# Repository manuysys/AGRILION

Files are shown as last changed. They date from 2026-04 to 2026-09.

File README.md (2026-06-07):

# 🌾 Agrilion

### Sistema inteligente de monitoreo para silobolsas

Agrilion es un sistema IoT diseñado para monitorear en tiempo real el
estado de granos almacenados en silobolsas, permitiendo detectar
condiciones de riesgo antes de que ocurran pérdidas económicas.

------------------------------------------------------------------------

## 🚀 Características principales

-   Comunicación LoRa de largo alcance\
-   Batería de larga duración (6--12 meses)\
-   Sensores de temperatura, humedad y gases\
-   Envío de datos cada 1--2 horas\
-   Visualización web\
-   Sistema de alertas tempranas\
-   Preparado para integración con IA

------------------------------------------------------------------------

## 🏗️ Arquitectura

Sensores → Dispositivo IoT (CubeCell) → LoRa → Gateway → Backend →
Dashboard

------------------------------------------------------------------------

## ⚙️ Tecnologías

-   Hardware: CubeCell + sensores\
-   Comunicación: LoRa / MQTT\
-   Backend: Firebase\
-   Frontend: Flutter Web\
-   Procesamiento: Python

------------------------------------------------------------------------

## ⚠️ Alertas

-   Humedad alta → posible filtración\
-   Temperatura elevada → actividad microbiana\
-   CO₂ alto → deterioro del grano

Estados: - Normal\
- Advertencia\
- Riesgo

------------------------------------------------------------------------

## 📊 Estado

-   Comunicación: OK\
-   Backend: OK\
-   Visualización: Básica\
-   Alertas: En desarrollo\
-   IA: En desarrollo

------------------------------------------------------------------------

## 🎯 Objetivo

Reducir pérdidas agrícolas mediante monitoreo inteligente y alertas
tempranas.

------------------------------------------------------------------------

## 👨‍💻 Autor

Juan Manuel Iglesias\
Proyecto Agrilion --- 2026

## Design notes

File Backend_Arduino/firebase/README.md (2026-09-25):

# Firebase Credentials

Este directorio contiene las credenciales de Firebase para el backend de AGRILION.

## ⚠️ IMPORTANTE

**NUNCA subas credenciales a Git.** Este directorio está protegido por `.gitignore`.

## Configuración

1. Ir a [Firebase Console](https://console.firebase.google.com/)
2. Seleccionar tu proyecto
3. Ir a **Project Settings** → **Service accounts**
4. Click en **Generate new private key**
5. Descargar el archivo JSON
6. Renombrarlo a `serviceAccountKey.json`
7. Colocarlo en este directorio: `Backend_Arduino/firebase/serviceAccountKey.json`

## Archivo Requerido

```
Backend_Arduino/firebase/serviceAccountKey.json
```

Este archivo es usado por:
- `MQTT_INFLUXDB_FIREBASE.py` — para actualizar datos categóricos en Firestore
- El script necesita permisos de escritura en las colecciones:
  - `sensors/{deviceId}` — estado de sensores
  - `users/{uid}/silos/{siloId}` — estado de silobolsas

## Estructura de Firestore

Ver `Inteligencia_Artificial/firestore.rules` para las reglas de seguridad completas.

### Colecciones usadas por el backend:

```
sensors/{deviceId}
  ├── ownerUid: string
  ├── siloId: string
  ├── active: boolean
  └── lastSeen: timestamp

users/{uid}/silos/{siloId}
  ├── estado: string (OK, RIESGO_MEDIO, RIESGO_ALTO)
  ├── alerta: string | null
  ├── score: number
  ├── evento: string | null
  ├── delta_co2: number
  └── ultima_actualizacion: timestamp
```

## Troubleshooting

### Error: "Firebase credentials not found"
Verificar que `firebase/serviceAccountKey.json` existe en este directorio.

### Error: "Permission denied"
Verificar que el service account tiene permisos de escritura en Firestore.

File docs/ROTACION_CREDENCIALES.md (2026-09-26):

# 🔐 Rotación de credenciales LoRaWAN (CubeCell / TTN)

Las credenciales OTAA del firmware estuvieron publicadas en el repositorio
(`devEui`, `appEui`, `appKey`). Ya se movieron a `secrets.h` (ignorado por git),
pero **hay que rotar el AppKey en TTN** para invalidar el que quedó público.

End device actual:

| Campo | Valor |
|---|---|
| End device ID | `smisia-cubecellab02s` |
| DevEUI | `70B3D57ED0076DC9` |
| JoinEUI (AppEUI) | `A2F42E5BA39F0F21` |
| Región | AU915 FSB2 |
| Activación | OTAA (LoRaWAN 1.0.2) |

---

## 1. Generar un AppKey nuevo en TTN

1. TTN Console → **Applications** → tu aplicación → **End devices** →
   `smisia-cubecellab02s`.
2. **General settings → Network layer → AppKey**.
3. Click en **Generate new AppKey** (o editar a mano un valor de 16 bytes) →
   **Save changes**.
4. Copiar el AppKey nuevo (hex de 32 caracteres).

> El DevEUI y el JoinEUI no hace falta cambiarlos (identifican el hardware y la
> aplicación; no son secretos). El AppKey es el secreto que se usa en el join.

## 2. Actualizar `secrets.h`

1. Copiar la plantilla si todavía no existe:

```bash
cd Backend_Arduino/Codigo_TransmisionLoraWAN_Sensores
copy secrets.h.example secrets.h
```

2. Editar `secrets.h` y pegar el AppKey nuevo:

```c
uint8_t devEui[] = { 0x70, 0xB3, 0xD5, 0x7E, 0xD0, 0x07, 0x6D, 0xC9 };
uint8_t appEui[] = { 0xA2, 0xF4, 0x2E, 0x5B, 0xA3, 0x9F, 0x0F, 0x21 };
uint8_t appKey[] = { 0x00, ... };  // ← reemplazar por el AppKey nuevo
```

> `secrets.h` está en `.gitignore`: nunca se sube al repo.

## 3. Reflashear y reiniciar la sesión

1. Abrir `Codigo_TransmisionLoraWAN_Sensores.ino` en Arduino IDE
   (placa CubeCell, región AU915).
2. Compilar y subir al dispositivo.
3. En TTN Console → End device → **Reset session** (borra la sesión vieja).
4. Encender el equipo: el log serie debe mostrar
   `DEVICE_STATE_INIT → JOIN → SEND → SLEEP`.
5. En TTN Console → **Live data** deben aparecer los uplinks con
   `decoded_payload` (temperatura, humedad, presion, co2, impacto, aceleracion).

## 4. Verificar que el payload se decodifica

El formatter tiene que estar pegado en
**TTN Console → Applications → Payload formatters → Uplink**:
copiar el contenido de `Backend_Arduino/TTN_Payload_Formatter.js`.

Payload esperado (11 bytes):

| Bytes | Campo | Escala |
|---|---|---|
| 0-1 | temperatura | ×100 (int16 BE) |
| 2-3 | humedad | ×100 (int16 BE) |
| 4-5 | presión | ×10 (int16 BE) |
| 6-7 | CO₂ | ppm (uint16 BE) |
| 8 | flag de impacto | 0/1 |
| 9-10 | aceleración | ×10 (uint16 BE) |

## 5. Chequeo rápido

- TTN Live data: llega un uplink cada ~20 s (configurable en `appTxDutyCycle`).
- HiveMQ: mensajes en `smisia/smisia-cubecellab02s`.
- InfluxDB: `SELECT * FROM "sensores" WHERE device = 'smisia-cubecellab02s' ORDER BY time DESC LIMIT 5`.
- Web: `/dashboard` y `/dashboard/silo/{id}` con la última lectura.

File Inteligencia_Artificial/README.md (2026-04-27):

# AGRILION 🌾

## Sistema ML de Análisis de Silobolsas Agrícolas

AGRILION es un sistema completo de Machine Learning para monitoreo y análisis predictivo de silobolsas agrícolas. Utiliza datos de sensores (temperatura, humedad, CO2) recolectados vía LoRa para detectar riesgos de deterioro del grano antes de que generen pérdidas.

---

## 📋 Características

- **Series Temporales**: Análisis de datos de sensores con LSTM
- **Detección de Anomalías**: 3 métodos (Z-Score, Moving Average, Isolation Forest) con consenso
- **Predicción**: Forecasting single-step y multi-step con LSTM
- **Scoring de Riesgo**: Motor ponderado (0-100) con reglas agronómicas
- **Alertas Inteligentes**: Alertas contextualizadas en español con recomendaciones
- **API REST**: FastAPI con endpoints de predicción y análisis
- **Visualización**: Gráficos profesionales con estilo dark theme

---

## 🏗️ Estructura del Proyecto

```
agrilion/
├── src/                         # Paquete principal
│   ├── __init__.py
│   ├── config.py                # Configuración centralizada
│   ├── data_loader.py           # Carga y limpieza de datos
│   ├── preprocessing.py         # Normalización y windowing LSTM
│   ├── anomaly_detection.py     # Detección de anomalías (3 métodos)
│   ├── lstm_model.py            # Modelo LSTM (TensorFlow/Keras)
│   ├── predictor.py             # Predicción y evaluación
│   ├── risk_engine.py           # Motor de riesgo agronómico
│   ├── alerts.py                # Sistema de alertas inteligentes
│   └── visualization.py         # Gráficos profesionales
├── api/                         # FastAPI
│   ├── __init__.py
│   ├── app.py                   # Aplicación FastAPI
│   ├── schemas.py               # Modelos Pydantic
│   └── routes.py                # Endpoints REST
├── data/                        # Datos
│   └── synthetic_generator.py   # Generador de datos sintéticos
├── models/                      # Modelos entrenados (.keras)
├── outputs/                     # Gráficos generados
├── tests/                       # Tests unitarios
│   └── test_pipeline.py
├── main.py                      # Pipeline completo
├── requirements.txt             # Dependencias
└── README.md
```

---

## 🚀 Instalación

```bash
# Clonar o navegar al proyecto
cd src

# Crear entorno virtual (recomendado)
python -m venv venv
venv\Scripts\activate          # Windows
# source venv/bin/activate    # Linux/Mac

# Instalar dependencias
pip install -r requirements.txt
```

---

## ▶️ Uso Rápido

### Pipeline Completo
```bash
# Ejecutar pipeline end-to-end (genera datos sintéticos si no existen)
python main.py

# Con datos propios
python main.py --data path/to/sensor_data.csv

# Personalizar entrenamiento
python main.py --epochs 100 --batch-size 64

# Usar modelo ya entrenado (sin re-entrenar)
python main.py --skip-training

# Sin gráficos
python main.py --no-plots
```

### API REST
```bash
# Iniciar la API
uvicorn api.app:app --reload --port 8000

# Documentación interactiva
# http://localhost:8000/docs
```

### Endpoints de la API

| Método | Endpoint | Descripción |
|---|---|---|
| `GET`  | `/api/v1/health` | Health check |
| `GET`  | `/api/v1/model/status` | Estado del modelo |
| `POST` | `/api/v1/predict` | Predicción de valores futuros |
| `POST` | `/api/v1/analyze` | Análisis completo (anomalías + riesgo + alertas) |

#### Ejemplo: Predicción
```bash
curl -X POST http://localhost:8000/api/v1/predict \
  -H "Content-Type: application/json" \
  -d '{
    "readings": [...],  # 24+ lecturas de sensores
    "steps": 6          # Pasos futuros a predecir
  }'
```

---

## 🧠 Arquitectura del Modelo LSTM

```
Input(24 timesteps, 3 features)
    → LSTM(128, return_sequences=True)
    → Dropout(0.2)
    → LSTM(64)
    → Dropout(0.2)
    → Dense(32, ReLU)
    → Dense(3)  # Predicción multivariable
```

- **Ventana de entrada**: 24 mediciones (~24 horas)
- **Optimizador**: Adam (lr=0.001)
- **Loss**: MSE
- **Callbacks**: EarlyStopping + ReduceLROnPlateau

---

## 🔍 Detección de Anomalías

| Método | Tipo | Parámetros |
|---|---|---|
| **Z-Score** | Estadístico | threshold=3.0σ |
| **Moving Average** | Tendencia local | window=12, threshold=2.0σ |
| **Isolation Forest** | ML no supervisado | contamination=5% |

**Consenso**: Una anomalía se confirma si ≥2 de 3 métodos la detectan.

---

## ⚠️ Motor de Riesgo

### Factores Ponderados

| Factor | Peso | Lógica |
|---|---|---|
| Humedad + Temperatura | 30% | Sinergia hongos/bacterias |
| CO2 | 25% | Actividad biológica / fermentación |
| Anomalías estadísticas | 20% | Proporción en ventana reciente |
| Desviación LSTM | 25% | Error de predicción normalizado |

### Niveles de Riesgo

| Score | Nivel | Significado |
|---|---|---|
| 0–30 | 🟢 NORMAL | Operación segura |
| 30–70 | 🟡 WARNING | Monitoreo recomendado |
| 70–100 | 🔴 CRITICAL | Acción urgente requerida |

---

## 📊 Gráficos Generados

1. **Series Temporales**: Visualización completa de sensores
2. **Predicciones vs Reales**: Overlay con métricas R²/MAE
3. **Anomalías Detectadas**: Series con puntos anómalos marcados
4. **Timeline de Riesgo**: Zonas de color por nivel
5. **Historial de Entrenamiento**: Loss y MAE por época

---

## 🧪 Tests

```bash
# Ejecutar todos los tests
python -m pytest tests/ -v

# Tests específicos
python -m pytest tests/test_pipeline.py::TestRiskEngine -v
```

---

## 📡 Formato de Datos

### CSV de Entrada
```csv
timestamp,temperature,humidity,co2,silo_id
2025-01-15 00:00:00,24.5,62.3,418.0,SILO_001
2025-01-15 01:00:00,23.8,64.1,422.5,SILO_001
...
```

### Columnas Requeridas
- `timestamp`: Fecha y hora (ISO 8601)
- `temperature`: Temperatura en °C
- `humidity`: Humedad relativa en %
- `co2`: Dióxido de carbono en ppm

---

## 🔧 Configuración

Todos los parámetros se centralizan en `src/config.py`:
- Umbrales agronómicos
- Arquitectura LSTM
- Parámetros de detección de anomalías
- Pesos del motor de riesgo
- Configuración de visualización

---

## 📄 Licencia

Proyecto privado — AGRILION © 2025

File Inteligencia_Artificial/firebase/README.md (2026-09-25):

# Firebase Credentials — AGRILION

Este directorio debe contener el archivo de credenciales del backend de Firebase.

## ⚠️ Importante

- `serviceAccountKey.json` **NO debe subirse a git** (ya está en `.gitignore`)
- Cada desarrollador debe descargar su propio archivo desde Firebase Console
- En producción, usar variables de entorno o un gestor de secretos (Google Cloud Secret Manager)

## Cómo obtener `serviceAccountKey.json`

### Paso 1: Ir a Firebase Console
1. Abrir https://console.firebase.google.com/
2. Seleccionar el proyecto **AGRILION** (o crear uno si no existe)

### Paso 2: Generar la clave privada
1. Ir a **Configuración del proyecto** (⚙️ → Configuración del proyecto)
2. Pestaña **Cuentas de servicio**
3. Click en **Generar nueva clave privada**
4. Descargar el JSON → renombrar a `serviceAccountKey.json`
5. Mover este archivo a este directorio:
   ```
   Inteligencia_Artificial/firebase/serviceAccountKey.json
   ```

### Paso 3: Habilitar Authentication
1. Firebase Console → **Authentication** → **Sign-in method**
2. Habilitar **Email/Password**
3. (Opcional) Habilitar Google Sign-in

### Paso 4: Crear Firestore Database
1. Firebase Console → **Firestore Database** → **Create database**
2. Elegir **modo de prueba** (para desarrollo) o **modo de producción** (para prod)
3. Seleccionar ubicación (recomendado: `southamerica-east1` para Argentina)

### Paso 5: Copiar reglas de Firestore
Las reglas están en `Inteligencia_Artificial/firestore.rules`. Subirlas manualmente desde:
1. Firebase Console → Firestore Database → Rules
2. Pegar el contenido de `firestore.rules`
3. Click en **Publicar**

## Estructura esperada

```
Inteligencia_Artificial/
├── firebase/
│   ├── README.md          ← este archivo
│   └── serviceAccountKey.json  ← descargar desde Firebase Console
└── firestore.rules         ← reglas para subir a Firebase
```

## Verificar que funciona

```bash
cd Inteligencia_Artificial
python -c "from src.services.firebase_service import get_firebase_service; fb = get_firebase_service(); print('OK' if fb else 'FALLÓ')"
```

Si imprime `OK`, Firebase está correctamente configurado.

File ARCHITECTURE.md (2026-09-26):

# AGRILION — Arquitectura del Sistema Integrado

> Documento técnico que describe cómo se conectan todos los componentes del sistema:
> Arduino → TTN → MQTT → InfluxDB/Firebase → AI API → Frontend Web

---

## 🏗️ Diagrama General

```
┌─────────────┐    LoRaWAN     ┌─────────┐    MQTT     ┌──────────┐
│  CubeCell   │ ──────────────▶│   TTN   │ ──────────▶│  HiveMQ  │
│  (Arduino)  │  868MHz/915MHz │ (Cloud) │            │ (Broker) │
└─────────────┘                └─────────┘            └────┬─────┘
                                                           │
                          ┌────────────────────────────────┤
                          │ smisia/#                        │
                          ▼                                ▼
                ┌──────────────────┐             ┌───────────────────┐
                │ TTN_MQTT.py      │             │ mqtt_to_ai_bridge │
                │ (Bridge TTN→MQTT)│             │ (MQTT → AI API)   │
                └──────────────────┘             └────────┬──────────┘
                                                          │
                    ┌─────────────────────┐               │ POST /api/v1/ingest
                    │MQTT_INFLUXDB_FIREBASE│               │
                    │    (Procesador)      │               ▼
                    ├─────────────────────┤    ┌──────────────────────┐
                    │ → InfluxDB (series) │    │   AI API (FastAPI)   │
                    │ → Firebase (estado) │    │                      │
                    └─────────────────────┘    │  /silos/overview     │
                                               │  /silos/{id}/history │
                          ┌────────────────┐   │  /chat               │
                          │   InfluxDB     │◀──│  /ingest             │
                          │   (datos crudos│   │  /analyze            │
                          └────────────────┘   └──────────┬───────────┘
                                                          │
                                                          ▼
                                               ┌──────────────────────┐
                                               │  Next.js Frontend    │
                                               │  (Dashboard Web)     │
                                               │                      │
                                               │  /dashboard          │
                                               │  /dashboard/ia       │
                                               │  /dashboard/alerts   │
                                               │  /dashboard/history  │
                                               └──────────────────────┘
```

---

## 📦 Componentes del Sistema

### 1. Arduino (CubeCell + Sensores)
- **Hardware**: CubeCell HTCC-AB02A + BME280 + MH-Z19B (CO2) + Acelerómetro
- **Función**: Lee temperatura, humedad, CO2 y aceleración cada ~20 min
- **Comunicación**: LoRaWAN → The Things Network (TTN)
- **Firmware**: `Backend_Arduino/Codigo_TransmisionLoraWAN_Sensores/`

### 2. The Things Network (TTN)
- **Función**: Gateway LoRaWAN que recibe los uplinks del CubeCell
- **Payload Formatter**: `Backend_Arduino/TTN_Payload_Formatter.js`
- **Output**: Publica en MQTT de TTN: `v3/{app_id}/devices/{device_id}/up`

### 3. TTN_MQTT.py (Bridge)
- **Función**: Se suscribe a TTN MQTT y republica en HiveMQ
- **Topic de salida**: `smisia/{device_id}`
- **Archivo**: `Backend_Arduino/TTN_MQTT.py`

### 4. MQTT_INFLUXDB_FIREBASE.py (Procesador Principal)
- **Función**: Lee de HiveMQ, evalúa riesgo, guarda en InfluxDB y Firebase
- **Motor de riesgo**: Score 0-100 basado en CO2, humedad, temperatura, aceleración
- **Config por grano**: Umbrales específicos para maíz, soja, trigo, girasol
- **Archivo**: `Backend_Arduino/MQTT_INFLUXDB_FIREBASE.py`

### 5. mqtt_to_ai_bridge.py (Puente a la IA)
- **Función**: Lee de HiveMQ y envía cada lectura a la AI API
- **Endpoint**: POST `http://localhost:8000/api/v1/ingest`
- **Archivo**: `Backend_Arduino/mqtt_to_ai_bridge.py`

### 6. AI API (FastAPI)
- **Función**: Ejecuta el modelo LSTM, detección de anomalías, y chatbot
- **Puerto**: 8000
- **Modelo**: LSTM entrenado con datos de sensores
- **Endpoints principales**:
  - `GET /api/v1/health` — Health check
  - `GET /api/v1/silos/overview` — Estado de todos los silos
  - `GET /api/v1/silos/{id}/history` — Historial de un silo
  - `GET /api/v1/silos/{id}/current` — Estado actual de un silo
  - `POST /api/v1/ingest` — Ingestar lectura y ejecutar pipeline ML
  - `POST /api/v1/chat` — Chatbot con LLM
- **Archivos**: `Inteligencia_Artificial/api/`

### 7. Frontend Web (Next.js)
- **Función**: Dashboard de monitoreo con visualización de datos
- **Puerto**: 3000
- **Modo mock**: Por defecto usa datos de prueba. Con `MOCK_MODE=false` llama a la AI API real.
- **Proxy**: `/api/ai/*` → `http://localhost:8000/api/v1/*` (sin CORS)
- **Archivos**: `paginaweb/`

---

## 🔑 Variables de Entorno

### Backend_Arduino/.env
```env
TTN_BROKER=eu1.cloud.thethings.network
TTN_PORT=8883
TTN_USER=tu_app_id@ttn
TTN_PASS=tu_api_key

HIVEMQ_BROKER=tu-cluster.hivemq.cloud
HIVEMQ_PORT=8883
HIVEMQ_USER=tu_user
HIVEMQ_PASS=tu_pass

INFLUX_URL=https://tu-region.influxdata.com
INFLUX_TOKEN=tu_token
INFLUX_ORG=tu_org
INFLUX_BUCKET=silobolsas

AI_API_URL=http://localhost:8000/api/v1
```

### Inteligencia_Artificial/.env
```env
# Chatbot (elegir uno):
OPENROUTER_API_KEY=sk-or-v1-tu_key    # Gratis → openrouter.ai
# OLLAMA_MODEL=llama3                   # Local → ollama.ai

# Datos reales (opcional):
INFLUX_URL=https://tu-region.influxdata.com
INFLUX_TOKEN=tu_token
INFLUX_ORG=tu_org
INFLUX_BUCKET=silobolsas
```

### paginaweb/.env.local
```env
NEXT_PUBLIC_MOCK_MODE=false
AI_API_URL=http://localhost:8000
```

---

## 🚀 Cómo Ejecutar Todo

### Paso 1: Entrenar el modelo (solo la primera vez)
```bash
cd Inteligencia_Artificial
python main.py --epochs 50
```

### Paso 2: Iniciar la AI API
```bash
cd Inteligencia_Artificial
cp .env.example .env   # Editar con tus credenciales
pip install -r requirements.txt
uvicorn api.app:app --reload --port 8000
```

### Paso 3: Iniciar el Frontend
```bash
cd paginaweb
cp .env.example .env.local   # Opcional: MOCK_MODE=false
npm install
npm run dev
```

### Paso 4: Iniciar los bridges IoT (3 terminales)
```bash
# Terminal 1: Bridge TTN → HiveMQ
cd Backend_Arduino
python TTN_MQTT.py

# Terminal 2: Procesador principal (InfluxDB + Firebase)
python MQTT_INFLUXDB_FIREBASE.py

# Terminal 3: Puente a la AI API
python mqtt_to_ai_bridge.py
```

### Verificación rápida
```bash
# 1. Health check de la API
curl http://localhost:8000/api/v1/health

# 2. Overview de silos
curl http://localhost:8000/api/v1/silos/overview

# 3. Chatbot
curl -X POST http://localhost:8000/api/v1/chat \
  -H "Content-Type: application/json" \
  -d '{"message": "¿Cómo están los silos?", "silo_id": "SILO_001"}'

# 4. Frontend
# Abrir http://localhost:3000/dashboard/ia
```

---

## 🤖 Chatbot — Estrategia de Costos

### Para Prototipo (GRATIS)

| Capa | Proveedor | Modelo | Costo |
|---|---|---|---|
| 1 | OpenRouter | `meta-llama/llama-3.1-8b-instruct:free` | $0 |
| 2 | Ollama (local) | `llama3` | $0 (requiere 8GB RAM) |
| 3 | Rule Engine | Determinístico | $0 (siempre funciona) |

**Recomendación**: Registrate en https://openrouter.ai/keys (gratis, sin tarjeta) y poné tu key en `.env`.

### Para Producción (Pago)

| Modelo | Costo/30K consultas | Justificación |
|---|---|---|
| GPT-4o-mini | ~$2.25/mes | Mejor razonamiento, function calling |
| Claude Haiku | ~$3.75/mes | Excelente en español, respuestas naturales |
| GPT-4o | ~$37.50/mes | Análisis complejos multi-silo |

**Justificación para migrar**:
- SLA garantizado (sin caídas inesperadas de modelos free)
- Latencia 2-5x menor
- Streaming de respuestas (mejor UX)
- Function calling (ej: "enviar alerta al técnico")
- Mayor contexto (128K tokens vs 8K de modelos free)

---

## 🧪 Testing y Pruebas

### Test sin hardware real
1. Iniciá la AI API (Paso 2)
2. Iniciá el Frontend (Paso 3) con `MOCK_MODE=false`
3. Abrí http://localhost:3000/dashboard/ia
4. Verificá que el indicador verde diga "AI API conectada"
5. Probá el chatbot: "¿Cómo están los silos?"

### Test con datos simulados en la API
```bash
# Inyectar lectura simulada
curl -X POST http://localhost:8000/api/v1/ingest \
  -H "Content-Type: application/json" \
  -d '{
    "silo_id": "TEST_001",
    "temperature": 28.5,
    "humidity": 72.3,
    "co2": 850
  }'
```

### Test con hardware real
1. Encender CubeCell → envía datos cada ~20s
2. Los 3 scripts de Backend_Arduino deben estar corriendo
3. Verificar en la consola del bridge: `✅ AI API OK | SILO_xxx | Risk: .../100`
4. Verificar en el frontend que los datos aparecen en el dashboard

---

## 📁 Estructura de Archivos Clave

```
AGRILION/
├── Backend_Arduino/
│   ├── TTN_MQTT.py              ← Bridge TTN → HiveMQ
│   ├── MQTT_INFLUXDB_FIREBASE.py ← Procesador principal
│   ├── mqtt_to_ai_bridge.py     ← NUEVO: Puente a AI API
│   ├── .env.example             ← NUEVO: Template de env vars
│   └── .env                     ← Credenciales reales
│
├── Inteligencia_Artificial/
│   ├── api/
│   │   ├── app.py               ← FastAPI app
│   │   ├── routes.py            ← MODIFICADO: + endpoints /silos/*
│   │   └── schemas.py           ← MODIFICADO: + ChatRequest/Response
│   ├── src/
│   │   ├── services/
│   │   │   ├── ai_service.py
│   │   │   └── influx_repository.py  ← NUEVO: Lee datos de InfluxDB
│   │   ├── chatbot/
│   │   │   ├── chatbot_service.py
│   │   │   ├── llm_client.py
│   │   │   └── rule_based_engine.py
│   │   └── config.py
│   ├── .env.example             ← NUEVO: Template de env vars
│   └── main.py
│
├── paginaweb/
│   ├── next.config.ts           ← MODIFICADO: + proxy /api/ai/*
│   ├── src/
│   │   ├── lib/
│   │   │   ├── ai-api.ts        ← NUEVO: Cliente HTTP para AI API
│   │   │   ├── data-service.ts  ← MODIFICADO: Usa AI API real
│   │   │   └── mock-data.ts
│   │   └── components/dashboard/
│   │       └── ia-client.tsx    ← MODIFICADO: Chatbot real + fallback
│   └── .env.local
│
└── ARCHITECTURE.md              ← ESTE ARCHIVO
```

---

## ⚠️ Errores Comunes y Soluciones

### 1. "AI API no disponible" en el frontend
- **Causa**: La AI API no está corriendo en puerto 8000
- **Solución**: `uvicorn api.app:app --reload --port 8000` en `Inteligencia_Artificial/`

### 2. "Modelo no disponible" en la API
- **Causa**: No se entrenó el modelo LSTM todavía
- **Solución**: `python main.py` en `Inteligencia_Artificial/`

### 3. El chatbot responde con reglas en lugar de IA
- **Causa**: No hay API key de OpenRouter configurada
- **Solución**: Agregar `OPENROUTER_API_KEY=sk-or-v1-...` en `.env`

### 4. El frontend muestra datos mock aunque MOCK_MODE=false
- **Causa**: La AI API no está accesible, el frontend cae a mock por seguridad
- **Solución**: Verificar que la API responde: `curl http://localhost:8000/api/v1/health`

### 5. "Connection refused" en mqtt_to_ai_bridge.py
- **Causa**: HiveMQ o la AI API no están disponibles
- **Solución**: Verificar credenciales de HiveMQ en `.env` y que la API esté corriendo

### 6. El modelo no predice bien con datos reales
- **Causa**: Fue entrenado con datos sintéticos
- **Solución**: Después de 2-4 semanas de datos reales en InfluxDB, re-entrenar:
  ```bash
  # Exportar datos reales de InfluxDB a CSV
  # Reemplazar data/sensor_data.csv
  # python main.py --epochs 100
  ```

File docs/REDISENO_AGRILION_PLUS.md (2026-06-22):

# Agrilion+ — Propuesta de Rediseño Completo

> Producto: monitoreo IoT de silobolsas (temperatura / humedad / CO₂) sobre LoRa.
> Foco: **decisión rápida en campo, mobile-first, claridad ante dato crítico**.

---

## 1. Sistema de diseño

### 1.1 Principios

1. **Decisión en 5 segundos** — el estado del sistema completo se lee sin scroll.
2. **Color = semántica, no decoración** — verde/amarillo/rojo SOLO para estado de salud.
3. **Jerarquía extrema** — la única métrica crítica (alerta crítica) ocupa el 40% del viewport.
4. **Mobile-first real** — todo lo que se ve en desktop cabe en mobile con reordenamiento, no con overflow horizontal.
5. **Interpretar antes que mostrar** — la UI dice "riesgo de fermentación", no "humedad 18%".

### 1.2 Paleta de color (semántica)

| Token | Valor | Uso |
| --- | --- | --- |
| `state.ok` | `#16a34a` | Silo estable, sin alertas |
| `state.warn` | `#f59e0b` | Atención, monitoreo reforzado |
| `state.critical` | `#dc2626` | Riesgo alto, intervención requerida |
| `state.offline`  | `#6b7280` | Sensor sin datos / batería agotada |
| `brand.primary`  | `#0B4D2C` | CTAs, identidad, navegación |
| `brand.accent` | `#2563eb` | Estados neutros del sistema, links |
| `surface.0` | `#ffffff` | Fondo app |
| `surface.1` | `#f5f7f6` | Fondo secciones, sidebar |
| `surface.dark` | `#0a1a10` | Hero, login, secciones de impacto |
| `border` | `#e5e7eb` | Bordes suaves |
| `text.primary` | `#111827` | Texto principal |
| `text.muted` | `#6b7280` | Texto secundario, timestamps |

**Regla dura:** ningún componente fuera del sistema de alertas usa rojo/amarillo/verde.

### 1.3 Tipografía

- **Sans:** `Inter` (UI general, números).
- **Mono:** `Geist Mono` (timestamps, IDs de silo, lecturas de sensor).
- Escala: `text-xs / sm / base / lg / xl / 2xl / 3xl / 4xl / 5xl`.
- Los números críticos (temperatura, humedad, score de riesgo) se renderizan a `font-mono` con `tabular-nums` para evitar saltos al actualizar.

### 1.4 Componentes base (design system)

| Componente | Variantes | Notas |
| --- | --- | --- |
| `StatusPill` | `ok` / `warn` / `critical` / `offline` | Único lugar donde se usan los 4 colores semánticos |
| `MetricCard` | icono + label + valor grande + delta + sparkline  | Para temp/humedad/CO₂ |
| `SiloCard` | estado + métricas + última lectura + tap target | Mínimo 96px de alto, tap target ≥ 44px² |
| `AlertCard` | severidad + silo + explicación humana + acciones  | La explicación es 1 línea, no un párrafo |
| `RiskGauge` | semicircular 0–100 con bandas semánticas | Para score de riesgo IA |
| `TimelineChart` | línea con bandas de umbral y eventos marcados | Recharts con `ReferenceLine` por umbral |
| `AnomalyBadge` | texto corto ("Fermentación", "Condensación") | Sin jerga ("Z-score > 2") |
| `EmptyState` | ilustración + acción | Sensor offline, sin alertas |
| `BottomSheet` | swipe-down dismiss | Solo mobile, usado para detalle de silo |
| `CommandBar` | búsqueda global por silo / alerta / comando | Cmd+K desktop, FAB mobile |

### 1.5 Estados UI obligatorios

Todo componente interactivo debe tener: `default` · `hover` · `active` · `disabled` · `loading` · `error`. Sin loading skeletons: usar el último dato conocido + indicador "actualizando…".

---

## 2. Arquitectura de pantallas

### 2.1 Inventario de rutas

| Ruta | Pantalla | Propósito |
| --- | --- | --- |
| `/` | Landing | Marketing, captura |
| `/login` | Login demo | Acceso simulado (1 click) |
| `/dashboard` | **Vista general** | Estado de toda la operación en una pantalla |
| `/dashboard/silo/[id]` | **Detalle de silobolsa** | Drill-down de un silo |
| `/dashboard/alerts` | **Bandeja de alertas** | Cola priorizada por severidad |
| `/dashboard/history` | Histórico | Series temporales largas, comparativas |
| `/dashboard/map` | Mapa de campo | Localización física de silobolsas |
| `/dashboard/ia` | Centro de IA | Análisis completo, recomendaciones |
| `/dashboard/settings` | Configuración | Umbrales, notificaciones, equipos |

### 2.2 Jerarquía de información (en `/dashboard`)

```
┌────────────────────────────────────────────────────────────┐
│  HEADER  · sistema OK · búsqueda · usuario                  │ 56px
├────────────────────────────────────────────────────────────┤
│  HERO STATUS (40% viewport)                                 │
│  ─────────────────────────                                   │
│  1 silobolsa en estado CRÍTICO                              │
│  SB-005 "Lote Sur A" · Humedad 18.2% · Temp 31.4°C          │
│  [Ir a la alerta →]                                         │
│                                                             │
│  + 3 alertas activas · 11/12 sensores online · 78% batería  │
├────────────────────────────────────────────────────────────┤
│  RANKING DE RIESGO (lista vertical, 1 card por silo)        │
│  ─────────────────────────────                              │
│  1. 🔴 SB-005  Crítico     · 18.2% / 31.4°C                │
│  2. 🟡 SB-003  Atención    · 15.8% / 27.2°C                │
│  3. 🟡 SB-010  Atención    · 17.0% / 28.1°C                │
│  4. 🟢 SB-001  Estable     · 12.3% / 24.5°C                │
│  …                                                          │
├────────────────────────────────────────────────────────────┤
│  BOTTOM NAV (solo mobile) · Resumen / Silobolsas / Alertas / IA │
└────────────────────────────────────────────────────────────┘
```

### 2.3 Vista de silobolsa (`/dashboard/silo/[id]`)

```
┌────────────────────────────────────────────┐
│ ← Volver     SB-005 "Lote Sur A"     ⋮      │
├────────────────────────────────────────────┤
│ RiskGauge 87/100  · Crítico                │
│ Explicación IA: "Posible fermentación..."  │
│ Recomendación: "Inspección presencial YA"  │
├────────────────────────────────────────────┤
│ Temperatura      Humedad        CO₂         │
│ 31.4°C ↑↑        18.2% ↑↑       820 ppm ↑   │
│ sparkline        sparkline      sparkline   │
├────────────────────────────────────────────┤
│ TimelineChart (24h, 3 series, eventos ▲)   │
│ Bandas de umbral: verde / amarillo / rojo   │
├────────────────────────────────────────────┤
│ Historial de alertas (3 items)              │
│ Estado sensor: ✓ online · batería 34% ⚠    │
└────────────────────────────────────────────┘
```

### 2.4 Bandeja de alertas

- **Agrupadas por severidad**, no por fecha.
- Cada alerta: silo afectado + explicación de 1 línea + acción sugerida + botones `Marcar vista` / `Ir al silo`.
- Filtros rápidos: `Críticas` / `Atención` / `Info` / `Resueltas`.
- Búsqueda libre por silo o tipo de alerta.

---

## 3. Mobile UX (reglas duras)

- **Tap targets ≥ 44×44 px.**
- **Bottom navigation 4 ítems** + FAB de acción rápida (buscar/crear alerta).
- **Sin tablas** — todo se renderiza como cards apiladas.
- **Sin hover** — todo lo que dependa de hover debe tener equivalente en tap largo o estado expanded.
- **Pull-to-refresh** explícito, sin auto-refresh en mobile (ahorra batería y datos).
- **Gráficos simplificados:** en `<640px` mostrar solo la serie más relevante + valor final + delta. El detalle va al drill-down.
- **Conectividad débil:** la última lectura conocida se muestra siempre; el timestamp distingue "hace 2 min" vs "hace 6 h" con código de color (gris → rojo).

---

## 4. Data visualization (criterios)

- **Un gráfico = una pregunta.** Nunca tres métricas superpuestas sin contexto.
- **Umbrales visuales siempre visibles** (`ReferenceLine` en Recharts) con etiqueta de valor.
- **Eventos marcados** con triángulos sobre la línea temporal; tap revela el evento.
- **Anomalías con fondo sutil** (banda translúcida) en el período afectado.
- **No usar donut charts para >5 categorías.** Riesgo por silo → barra horizontal ordenada.
- **Loading = último valor + animación "actualizando…"**, no spinner a pantalla completa.
- **Empty states ilustrados** cuando no hay datos ("Aún no se recibieron lecturas del sensor SB-011").

---

## 5. Componentes frontend (Propuesta React)

```
src/
├── app/
│   ├── dashboard/
│   │   ├── page.tsx                    # Vista general
│   │   ├── silo/[id]/page.tsx
│   │   ├── alerts/page.tsx
│   │   ├── history/page.tsx
│   │   ├── map/page.tsx
│   │   ├── ia/page.tsx
│   │   └── settings/page.tsx
│   └── (vistas auxiliares)
├── components/
│   ├── ui/                             # Primitivas (shadcn-style)
│   │   ├── status-pill.tsx
│   │   ├── metric-card.tsx
│   │   ├── risk-gauge.tsx
│   │   ├── alert-card.tsx
│   │   ├── timeline-chart.tsx
│   │   ├── bottom-sheet.tsx
│   │   └── command-bar.tsx
│   ├── dashboard/                      # Compuestos del dominio
│   │   ├── DashboardHero.tsx           # Estado crítico arriba
│   │   ├── RiskRanking.tsx             # Lista priorizada
│   │   ├── SiloCard.tsx
│   │   ├── SiloDetailHeader.tsx
│   │   ├── AnomalyBadge.tsx
│   │   ├── AlertQueue.tsx
│   │   └── AIInterpretationPanel.tsx
│   └── layout/                         # AppShell, BottomNav, etc.
├── lib/
│   ├── data-service.ts
│   ├── interpretation.ts               # "humedad 18% + temp 31°C" → "fermentación"
│   ├── thresholds.ts                   # Constantes de umbrales
│   └── formatters.ts                   # "hace 2 min", "18.2 %"
└── types/
    └── index.ts                        # SiloBag, Alert, Reading, RiskScore
```

---

## 6. User flows

### 6.1 Detección de una alerta crítica (caso feliz)

```
Productor abre la app
   ↓ (3 seg)
Ve en HERO STATUS: "SB-005 crítico · Humedad 18.2%"
   ↓ (1 tap, 1 seg)
Tap → push a /dashboard/silo/SB-005
   ↓ (5 seg)
Lee explicación IA: "Posible fermentación"
Ve recomendación: "Inspección presencial YA"
   ↓ (1 tap)
Tap "Llamar a técnico" / "Marcar en curso"
```

Tiempo total: **<15 segundos** desde "abrí la app" hasta "acción tomada".

### 6.2 Revisión matutina de campo

```
Productor abre la app
   ↓
Ve ranking de 12 silos ordenado por riesgo
   ↓
Scroll rápido: los 3 amarillos/rojos saltan a la vista
   ↓
Tap en SB-003 (amarillo) → confirma tendencia, no requiere acción
   ↓
Vuelve → tap SB-005 (rojo) → llama al técnico
   ↓
Chat con IA: "¿qué silos tienen batería baja?"
   ↓
Recibe: "SB-005 (34%) y SB-010 (45%)"
```

### 6.3 Silo con sensor offline

```
Usuario ve SB-011 con pill `offline` (gris)
   ↓
Tap → pantalla detalle muestra:
   "Última lectura hace 14 h. Posible batería agotada o pérdida de señal."
   ↓
CTA: "Marcar para revisión" + "Ver en mapa"
```

---

## 7. Capa de IA / interpretación (cómo convertir datos en decisiones)

### 7.1 Principio

> La UI **nunca** muestra un valor crudo sin una interpretación al lado.

### 7.2 Ejemplos de mapeo dato → explicación

| Lecturas | Etiqueta mostrada | Acción sugerida |
| --- | --- | --- |
| Humedad > 17% y Temp > 28°C | **Fermentación probable** | Inspección presencial |
| Humedad > 16% con Temp estable | **Condensación** | Monitoreo reforzado |
| CO₂ > 800 ppm + Temp ↑ | **Actividad biológica**| Preparar aireación |
| Batería < 20% | **Batería crítica** | Reemplazo de sensor |
| Sin datos > 6h | **Sensor sin señal** | Revisar in situ |
| ΔTemp > 3°C en 6h | **Pico térmico** | Inspección zona del sensor |
| 3+ alertas warning en 24h | **Tendencia adversa**  | Plan de contingencia |

### 7.3 Chat IA

- Comandos naturales: "¿qué silos están en riesgo?", "resumen de la última semana", "explicá la alerta de SB-005".
- Respuestas en español, máximo 3 oraciones, siempre con CTA: `[Ver silo]`.
- Si no entiende: muestra 3 sugerencias de comandos.

### 7.4 Score de riesgo (0–100)

- Calculado en backend (ya existe en `Inteligencia_Artificial/src/risk_engine.py`).
- Render: `RiskGauge` con bandas `0–30` verde · `30–35` amarillo · `>35` rojo.
- Bandas vienen de la convención ya documentada en `Inteligencia_Artificial/README.md` (≤30 normal, 30–35 warning, >35 danger).
- **Nunca mostrar el score sin la etiqueta de banda al lado.**

---

## 8. Mejoras inteligentes (AI UX) adicionales

1. **Predicción de riesgo a 24h** — banda de incertidumbre en el `TimelineChart` (mock hoy, real cuando el LSTM esté en producción).
2. **Comparación con silos vecinos** — "SB-005 está 2°C por encima de la media de la zona".
3. **Detección de silencio** — alerta proactiva si un sensor deja de reportar (no solo esperar a que el dato falte).
4. **Resumen diario push** — "Hoy: 1 silo crítico, 2 en atención, todos los demás estables."
5. **Modo campo** — alto contraste, tipografía 1.2×, sin animaciones (toggle en settings).
6. **Modo offline-first** — cache de últimas 24h en `IndexedDB`, lectura instantánea sin red.
7. **Reconocimiento por voz** (futuro) — "¿cómo está el lote sur?" devuelve respuesta hablada.

---

## 9. Métricas de éxito del rediseño

| Métrica | Baseline actual | Meta |
| --- | --- | --- |
| Tiempo medio desde abrir app → primera decisión | ~25 s | **<5 s** |
| % de alertas críticas accionadas < 15 min | desconocido | **>90%** |
| Errores de interpretación de estado | frecuentes | **<5%** |
| Uso en mobile (sesiones iniciadas) | bajo | **>60%** |
| NPS productor | n/a | **>50** |

---

## 10. Roadmap de implementación

**Fase 1 — fundaciones (1 sprint)**
- Design tokens centralizados (`tailwind.config.ts` extensions).
- `StatusPill`, `MetricCard`, `SiloCard`, `AlertCard` primitivos.
- Reemplazar colores hardcodeados en componentes existentes.

**Fase 2 — dashboard rediseñado (1 sprint)**
- `DashboardHero` con alerta crítica destacada.
- `RiskRanking` ordenado por score.
- `SiloDetailHeader` con `RiskGauge` + interpretación IA.
- `TimelineChart` con `ReferenceLine` de umbrales y eventos.

**Fase 3 — mobile-first (1 sprint)**
- `BottomNav`, `BottomSheet`, pull-to-refresh.
- Gráficos simplificados en breakpoints `<sm`.
- PWA manifest + service worker (offline cache).

**Fase 4 — capa IA UX (1 sprint)**
- `lib/interpretation.ts` con todas las reglas de mapeo.
- `AIInterpretationPanel` en detalle de silo.
- Chat widget con comandos sugeridos.

**Fase 5 — pulido (continuo)**
- Modo campo, accesibilidad (WCAG AA), animaciones solo cuando aportan.

---

## 11. Decisiones de product designer (registro)

- **Bottom nav > sidebar en mobile:** la operación principal es "ver silos", no "configurar". La nav refleja esa jerarquía.
- **Hero status en dashboard > lista de silos:** la pregunta más frecuente del productor es "¿hay algo roto?", no "¿cómo está el silo 7?". Lo urgente gana el prime real estate.
- **Una sola vista para alertas, no popups:** las alertas son el producto, no una notificación. merecen una ruta propia.
- **No mostrar lecturas "raw" sin interpretación:** rompe el principio de "decisión en 5 s". Si el productor tiene que pensar, perdimos.
- **Sin dark mode por ahora:** el uso primario es diurno en campo. Si se justifica, se agrega en fase 5.

---

## 12. Accesibilidad

- Contraste mínimo AA en todos los textos (4.5:1).
- Estados no comunicados solo por color: siempre un icono + texto junto al pill de estado.
- `aria-live="polite"` en actualizaciones de métricas.
- Navegación completa por teclado en desktop.
- Soporte de `prefers-reduced-motion` (ya implementado en `globals.css`).
- Tamaño mínimo de texto: 14px en mobile, 16px en desktop.

---

## 13. Cómo se integra con lo existente

- **Mock mode** sigue funcionando: el rediseño consume la misma capa `data-service.ts` que ya existe. Los nuevos componentes se renderizan con los mismos `mockSilobags` / `mockAlerts`.
- **Backend Arduino** sin cambios: `Inteligencia_Artificial/src/risk_engine.py` ya calcula el score; la nueva UI lo consume desde `data-service.ts` como hoy.
- **Tipos** se extienden en `src/types/index.ts` sin romper los actuales (solo se agregan campos opcionales).
- **Componentes UI nuevos** viven en `src/components/ui/` siguiendo la convención shadcn, sin tocar los `src/components/dashboard/*` existentes hasta la fase de migración.

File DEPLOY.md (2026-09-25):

# 🚀 Guía de Despliegue de Agrilion

Este documento describe cómo desplegar el sistema completo de Agrilion usando Docker.

## 📋 Requisitos Previos

- **Docker** 20.10+
- **Docker Compose** 2.0+
- **Git** (para clonar el repositorio)
- Credenciales de:
  - [Groq](https://console.groq.com/keys) (chatbot gratuito)
  - [InfluxDB Cloud](https://cloud2.influxdata.com/) (o local)
  - [HiveMQ Cloud](https://www.hivemq.com/) (o broker MQTT local)
  - [Firebase](https://console.firebase.google.com/) (Auth + Firestore)
  - [The Things Network](https://www.thethingsnetwork.org/) (LoRaWAN)

## 🏗️ Arquitectura del Sistema

```
┌─────────────────┐
│  CubeCell       │ (Sensor LoRaWAN)
│  (Arduino)      │
└────────┬────────┘
         │ LoRaWAN
         ↓
┌─────────────────┐
│  The Things     │
│  Network (TTN)  │
└────────┬────────┘
         │ MQTT
         ↓
┌─────────────────┐
│  HiveMQ Cloud   │
│  (MQTT Broker)  │
└────────┬────────┘
         │ MQTT
         ↓
┌─────────────────────────────────────────────────────────────┐
│  Backend Scripts (Python) — 3 procesos en paralelo          │
│                                                             │
│  1. TTN_MQTT.py                                             │
│     → Republish de TTN a HiveMQ                             │
│                                                             │
│  2. MQTT_INFLUXDB_FIREBASE.py                               │
│     → Lecturas numéricas → InfluxDB (time-series)           │
│     → Estado de sensores/silos → Firebase (categorical)     │
│                                                             │
│  3. mqtt_to_ai_bridge.py                                    │
│     → Lecturas → AI API /ingest endpoint                    │
└────────┬────────────────────────────────────────────────────┘
         │
         ├──────────────────┐
         ↓                  ↓
┌─────────────────┐  ┌─────────────────┐
│  InfluxDB       │  │  Firebase       │
│  (Time-Series)  │  │  (Firestore)    │
│                 │  │                 │
│ - temperature   │  │ - users         │
│ - humidity      │  │ - silos         │
│ - co2           │  │ - sensors       │
│ - score         │  │ - alerts        │
└─────────────────┘  └─────────────────┘
         ↑                  ↑
         │                  │
┌─────────────────────────────────────────────────────────────┐
│  AI API (FastAPI)                                           │
│                                                             │
│  - /api/v1/chat → Groq LLM (chatbot)                        │
│  - /api/v1/silos/overview → Datos de silos                  │
│  - /api/v1/silos/{id}/history → Historial                   │
│  - /api/v1/auth/register → Registro de usuarios             │
│  - /api/v1/auth/verify → Verificación de tokens             │
│  - LSTM model (anomalías + predicciones)                    │
└────────┬────────────────────────────────────────────────────┘
         │ HTTP
         ↓
┌─────────────────┐
│  Web Frontend   │ (Next.js)
│  (React)        │
└─────────────────┘
         │
         ↓
┌─────────────────┐
│  Android App    │ (Kotlin + Retrofit)
│  (Móvil)        │
└─────────────────┘
```

## 📦 Estructura del Proyecto

```
AGRILION/
├── Backend_Arduino/          # Scripts Python (MQTT → InfluxDB + Firebase)
│   ├── TTN_MQTT.py
│   ├── MQTT_INFLUXDB_FIREBASE.py
│   ├── mqtt_to_ai_bridge.py
│   ├── .env.example
│   ├── Dockerfile
│   ├── supervisord.conf
│   └── requirements.txt
│
├── Inteligencia_Artificial/  # AI API (FastAPI + TensorFlow)
│   ├── api/
│   │   ├── app.py
│   │   ├── routes.py
│   │   └── schemas.py
│   ├── src/
│   │   ├── chatbot/
│   │   │   ├── llm_client.py      # Groq + OpenRouter + Rule Engine
│   │   │   └── chatbot_service.py
│   │   ├── services/
│   │   │   ├── firebase_service.py  # Auth + Firestore
│   │   │   └── influx_repository.py # Lecturas de InfluxDB
│   │   └── ...
│   ├── firebase/                    # serviceAccountKey.json (NO subir a git)
│   ├── .env.example
│   ├── Dockerfile
│   └── requirements.txt
│
├── paginaweb/                # Frontend Next.js
│   ├── src/
│   │   ├── app/
│   │   │   ├── dashboard/
│   │   │   │   ├── layout.tsx
│   │   │   │   ├── page.tsx
│   │   │   │   └── ia/page.tsx
│   │   │   └── ...
│   │   └── components/
│   │       └── dashboard/
│   │           └── ia-client.tsx    # Chat UI
│   ├── .env.local
│   ├── Dockerfile
│   └── next.config.ts
│
├── AppCelular/               # App Android (Kotlin)
│   └── app/src/main/
│       ├── java/com/example/app1/
│       │   ├── data/
│       │   │   └── ChatApiServiceBaseDeDatos.kt
│       │   └── ui/screens/
│       │       ├── DashboardScreen.kt
│       │       └── ...
│       └── AndroidManifest.xml
│
├── docker-compose.yml        # Orquestación de servicios
├── MOBILE_INTEGRATION.md     # Guía de integración móvil
└── ARCHITECTURE.md           # Este documento
```

## 🔧 Configuración Paso a Paso

### 1. Clonar el Repositorio

```bash
git clone https://github.com/tu-usuario/agrilion.git
cd agrilion
```

### 2. Configurar Variables de Entorno

#### Backend Arduino
```bash
cd Backend_Arduino
cp .env.example .env
```

Editar `.env`:
```env
# TTN (The Things Network)
TTN_BROKER=eu1.cloud.thethings.network
TTN_PORT=8883
TTN_USER=tu-app-id@ttn
TTN_PASS=tu-api-key

# HiveMQ Cloud
HIVEMQ_BROKER=tu-cluster.hivemq.cloud
HIVEMQ_PORT=8883
HIVEMQ_USER=tu-usuario
HIVEMQ_PASS=tu-password

# InfluxDB Cloud
INFLUX_URL=https://tu-region-1-1.aws.cloud2.influxdata.com
INFLUX_TOKEN=tu-token
INFLUX_ORG=tu-org
INFLUX_BUCKET=silobolsas
```

#### Inteligencia Artificial
```bash
cd ../Inteligencia_Artificial
cp .env.example .env
```

Editar `.env`:
```env
# Groq (chatbot — GRATIS sin tarjeta de crédito)
# Obtener en: https://console.groq.com/keys
GROQ_API_KEY=gsk_tu_key_aqui

# OpenRouter (fallback — opcional)
OPENROUTER_API_KEY=sk-or-v1-tu_key_aqui

# InfluxDB (mismas credenciales que Backend)
INFLUX_URL=https://tu-region-1-1.aws.cloud2.influxdata.com
INFLUX_TOKEN=tu-token
INFLUX_ORG=tu-org
INFLUX_BUCKET=silobolsas

# Firebase (datos categóricos)
FIREBASE_CREDENTIALS_PATH=firebase/serviceAccountKey.json
```

#### Frontend Web
```bash
cd ../paginaweb
cp .env.example .env.local
```

Editar `.env.local`:
```env
NEXT_PUBLIC_MOCK_MODE=false
AI_API_URL=http://localhost:8000
```

### 3. Configurar Firebase

1. Ir a [Firebase Console](https://console.firebase.google.com/)
2. Crear un nuevo proyecto (o usar uno existente)
3. Habilitar **Authentication** → Email/Password
4. Habilitar **Firestore Database** (modo producción)
5. Ir a **Project Settings** → **Service accounts** → **Generate new private key**
6. Descargar el archivo JSON
7. Renombrarlo a `serviceAccountKey.json`
8. Colocarlo en:
   ```
   Inteligencia_Artificial/firebase/serviceAccountKey.json
   Backend_Arduino/firebase/serviceAccountKey.json
   ```

### 4. Estructura de Firestore

Crear las siguientes colecciones en Firestore (o dejar que la API las cree automáticamente):

```
users/
  └── {uid}/
      ├── email: string
      ├── name: string
      ├── phone: string
      ├── company: string
      ├── createdAt: timestamp
      ├── role: "admin" | "user"
      │
      ├── silos/
      │   └── {silo_id}/
      │       ├── name: string
      │       ├── grainType: string
      │       ├── location: string
      │       ├── tons: number
      │       ├── createdAt: timestamp
      │       └── sensors/
      │           └── {device_id}/
      │               ├── deviceId: string
      │               ├── active: boolean
      │               ├── battery: number
      │               └── lastSeen: timestamp
      │
      └── alerts/
          └── {alert_id}/
              ├── siloId: string
              ├── level: "critical" | "high" | "medium" | "low"
              ├── title: string
              ├── message: string
              ├── timestamp: timestamp
              └── acknowledged: boolean

sensors/ (colección global para lookup rápido)
  └── {device_id}/
      ├── ownerUid: string
      ├── siloId: string
      ├── siloPath: string
      ├── active: boolean
      └── lastSeen: timestamp
```

### 5. Configurar Reglas de Firestore

En Firebase Console → Firestore → Rules:

```javascript
rules_version = '2';
service cloud.firestore {
  match /databases/{database}/documents {
    // Users can only read/write their own data
    match /users/{userId} {
      allow read, write: if request.auth != null && request.auth.uid == userId;
      
      match /silos/{siloId} {
        allow read, write: if request.auth.uid == userId;
        
        match /sensors/{sensorId} {
          allow read, write: if request.auth.uid == userId;
        }
      }
      
      match /alerts/{alertId} {
        allow read, write: if request.auth.uid == userId;
      }
    }
    
    // Sensors collection (global lookup) — solo backend puede escribir
    match /sensors/{deviceId} {
      allow read: if request.auth != null;
      allow write: if false; // Solo el backend (service account) puede escribir
    }
  }
}
```

### 6. Entrenar el Modelo LSTM (Primera Vez)

```bash
cd Inteligencia_Artificial
python main.py
```

Esto generará:
- `models/lstm_agrilion.keras` (modelo entrenado)
- `models/scaler.pkl` (normalizador)

### 7. Levantar con Docker Compose

```bash
# Desde la raíz del proyecto
docker-compose up -d
```

Esto iniciará:
- ✅ AI API en http://localhost:8000
- ✅ Web Frontend en http://localhost:3000
- ✅ Backend scripts (3 procesos en paralelo)

### 8. Verificar que Todo Funciona

```bash
# Health check de la API
curl http://localhost:8000/api/v1/health

# Ver logs de los contenedores
docker-compose logs -f ai-api
docker-compose logs -f web
docker-compose logs -f backend
```

## 🧪 Testing

### 1. Probar el Chatbot

```bash
curl -X POST http://localhost:8000/api/v1/chat \
  -H "Content-Type: application/json" \
  -d '{
    "message": "¿Cómo está el sistema?",
    "silo_id": "SILO_001",
    "session_id": "test-session"
  }'
```

Debería devolver una respuesta del chatbot usando Groq.

### 2. Probar Registro de Usuario

```bash
curl -X POST http://localhost:8000/api/v1/auth/register \
  -H "Content-Type: application/json" \
  -d '{
    "email": "test@example.com",
    "password": "test123456",
    "name": "Test User"
  }'
```

### 3. Probar el Frontend

Abrir http://localhost:3000 en el navegador.

### 4. Probar la App Móvil

Ver [MOBILE_INTEGRATION.md](MOBILE_INTEGRATION.md) para detalles.

## 🔄 Actualizaciones

### Actualizar Código
```bash
git pull origin main
docker-compose down
docker-compose build --no-cache
docker-compose up -d
```

### Re-entrenar Modelo
```bash
cd Inteligencia_Artificial
python main.py --epochs 100
docker-compose restart ai-api
```

## 🐛 Troubleshooting

### Problema: "Firebase no disponible"
**Solución:** Verificar que `firebase/serviceAccountKey.json` existe y es válido.

### Problema: "GROQ_API_KEY not set"
**Solución:** Verificar que `GROQ_API_KEY` está en `Inteligencia_Artificial/.env`.

### Problema: "InfluxDB connection failed"
**Solución:** Verificar credenciales de InfluxDB y que el bucket existe.

### Problema: "MQTT connection failed"
**Solución:** Verificar credenciales de HiveMQ y que el broker está accesible.

### Problema: "Model not found"
**Solución:** Ejecutar `python main.py` en `Inteligencia_Artificial/` para entrenar el modelo.

## 📊 Monitoreo

### Logs en Tiempo Real
```bash
docker-compose logs -f
```

### Métricas de Docker
```bash
docker stats
```

### Health Checks
```bash
# API
curl http://localhost:8000/api/v1/health

# Web
curl -I http://localhost:3000

# InfluxDB (si es local)
curl http://localhost:8086/health
```

## 🔐 Seguridad

### Producción

Para producción, considerar:

1. **HTTPS**: Usar un reverse proxy (nginx/traefik) con certificados SSL
2. **Secrets**: Usar Docker Secrets o un servicio de gestión de secretos
3. **Firewall**: Restringir acceso a puertos internos
4. **Rate Limiting**: Implementar rate limiting en la API
5. **CORS**: Configurar CORS correctamente en la API
6. **Backups**: Configurar backups automáticos de InfluxDB y Firestore

### Variables de Entorno en Producción

```env
# Usar variables de entorno en lugar de archivos .env
docker-compose up -d \
  -e GROQ_API_KEY=gsk_... \
  -e INFLUX_URL=... \
  -e INFLUX_TOKEN=...
```

## 📈 Escalabilidad

### Horizontal Scaling

Para escalar horizontalmente:

1. **AI API**: Múltiples instancias detrás de un load balancer
2. **Backend**: Separar los 3 scripts en contenedores independientes
3. **InfluxDB**: Usar InfluxDB Cloud o cluster
4. **Firebase**: Ya es escalable (managed service)

### Vertical Scaling

Aumentar recursos de los contenedores en `docker-compose.yml`:

```yaml
services:
  ai-api:
    deploy:
      resources:
        limits:
          cpus: '2.0'
          memory: 4G
```

## 📚 Recursos Adicionales

- [Documentación de Groq](https://console.groq.com/docs)
- [Documentación de Firebase](https://firebase.google.com/docs)
- [Documentación de InfluxDB](https://docs.influxdata.com/)
- [Documentación de FastAPI](https://fastapi.tiangolo.com/)
- [Documentación de Next.js](https://nextjs.org/docs)
- [Documentación de Docker](https://docs.docker.com/)

---

**Última actualización:** 2026-08-18  
**Versión:** 2.0.0

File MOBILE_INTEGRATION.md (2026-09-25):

# 📱 Integración de la App Móvil con Agrilion

## Arquitectura

```
┌─────────────────┐         HTTP/HTTPS         ┌──────────────────┐
│  Android App    │  ←──────────────────────→  │   AI API         │
│  (Kotlin)       │   Retrofit + Firebase Auth │   (FastAPI)      │
└─────────────────┘                            └──────────────────┘
         ↑                                              ↑
         │ Firebase SDK (directo)                       │ Firebase Admin SDK
         ↓                                              ↓
┌─────────────────────────────────────────────────────────────────┐
│                    Firebase Cloud                               │
│  ├── Auth (usuarios)                                           │
│  └── Firestore (silos, sensores, alertas — datos categóricos) │
└─────────────────────────────────────────────────────────────────┘
```

## URLs de la API

### Desarrollo (emulador Android)
```
BASE_URL = http://10.0.2.2:8000
```
`10.0.2.2` es el alias del host local de la PC visto desde el emulador Android.

### Dispositivo físico (misma red WiFi)
```
BASE_URL = http://<IP_DE_TU_PC>:8000
```
Reemplazá `<IP_DE_TU_PC>` con la IP local de tu computadora (ej: `192.168.1.100`).

### Producción
```
BASE_URL = https://api.agrilion.app
```

## Endpoints Disponibles

### 🔐 Autenticación

#### `POST /api/v1/auth/register`
Registra un nuevo usuario.

**Request:**
```json
{
  "email": "juan@example.com",
  "password": "securepass123",
  "name": "Juan Pérez",
  "phone": "+5491123456789",
  "company": "Agrícola SRL"
}
```

**Response:**
```json
{
  "status": "ok",
  "user": {
    "uid": "abc123...",
    "email": "juan@example.com",
    "name": "Juan Pérez",
    "createdAt": "2026-01-15T10:30:00"
  }
}
```

#### `POST /api/v1/auth/verify`
Verifica un Firebase ID token (útil después del login en la app).

**Request:**
```json
{
  "idToken": "eyJhbGciOiJSUzI1NiIsInR5cCI6IkpXVCJ9..."
}
```

**Response:**
```json
{
  "status": "ok",
  "uid": "abc123...",
  "email": "juan@example.com",
  "profile": {
    "name": "Juan Pérez",
    "phone": "+5491123456789",
    "company": "Agrícola SRL",
    "role": "user"
  }
}
```

### 🌾 Silos

#### `GET /api/v1/users/{uid}/silos`
Lista todos los silos del usuario.

**Response:**
```json
{
  "status": "ok",
  "silos": [
    {
      "silo_id": "SB-12345",
      "name": "Silo Norte",
      "grainType": "soja",
      "location": "Lote 5",
      "tons": 120.5,
      "createdAt": "...",
      "sensors": [
        {
          "deviceId": "cubecell-001",
          "active": true,
          "battery": 95,
          "lastSeen": "..."
        }
      ],
      "activeSensors": 1
    }
  ],
  "total": 1
}
```

#### `POST /api/v1/users/{uid}/silos`
Crea una nueva silobolsa.

**Request:**
```json
{
  "name": "Silo Sur",
  "grain_type": "maíz",
  "location": "Lote 8",
  "tons": 150.0
}
```

**Response:**
```json
{
  "status": "ok",
  "silo_id": "SB-12346"
}
```

#### `GET /api/v1/users/{uid}/silos/{silo_id}`
Obtiene detalle de un silo específico.

### 📡 Sensores

#### `POST /api/v1/users/{uid}/silos/{silo_id}/sensors`
Registra un sensor y lo asocia a un silo.

**Request:**
```json
{
  "device_id": "cubecell-002",
  "battery": 98
}
```

#### `GET /api/v1/sensors/{device_id}`
Obtiene info de un sensor por device_id (lookup global).

### 🤖 Chatbot

#### `POST /api/v1/chat`
Envía un mensaje al chatbot de IA.

**Request:**
```json
{
  "message": "¿Cómo está el silo SB-12345?",
  "silo_id": "SB-12345",
  "session_id": "android-client"
}
```

**Response:**
```json
{
  "response": "El silo SB-12345 presenta condiciones normales...",
  "session_id": "android-client",
  "latency_ms": 245.3,
  "context_used": {...}
}
```

### 🔔 Alertas

#### `GET /api/v1/users/{uid}/alerts`
Lista alertas del usuario (opcionalmente filtrar por `?acknowledged=false`).

#### `POST /api/v1/users/{uid}/alerts/{alert_id}/acknowledge`
Marca una alerta como reconocida.

## Flujo de Integración en la App

### 1. Login / Registro
```kotlin
// Usar Firebase Auth directamente (SDK de Firebase en la app)
FirebaseAuth.getInstance().signInWithEmailAndPassword(email, password)
    .addOnCompleteListener { task ->
        if (task.isSuccessful) {
            val user = FirebaseAuth.getInstance().currentUser
            val uid = user?.uid
            
            // Obtener ID token para enviar al backend
            user?.getIdToken(true)?.addOnCompleteListener { tokenTask ->
                val idToken = tokenTask.result?.token
                
                // Verificar con el backend
                retrofit.post("/api/v1/auth/verify", mapOf("idToken" to idToken))
            }
        }
    }
```

### 2. Cargar Silos
```kotlin
// Después del login, cargar silos del usuario
val uid = FirebaseAuth.getInstance().currentUser?.uid
retrofit.get("/api/v1/users/$uid/silos")
    .enqueue(object : Callback<SilosResponse> {
        override fun onResponse(...) {
            // Actualizar UI con lista de silos
        }
    })
```

### 3. Chatbot
```kotlin
// Enviar mensaje al chatbot
val request = ChatRequest(
    message = "¿Hay alguna alerta activa?",
    silo_id = "SB-12345",
    session_id = "android-${System.currentTimeMillis()}"
)

retrofit.post("/api/v1/chat", request)
    .enqueue(object : Callback<ChatResponse> {
        override fun onResponse(...) {
            // Mostrar respuesta en la UI
        }
    })
```

### 4. Leer Datos de Sensores (Opcional — Firebase Realtime)
La app puede escuchar cambios en Firestore directamente:
```kotlin
val db = FirebaseFirestore.getInstance()
val uid = FirebaseAuth.getInstance().currentUser?.uid

db.collection("users").document(uid!!)
    .collection("silos")
    .addSnapshotListener { snapshot, error ->
        // Actualizar UI cuando cambian los silos
    }
```

## Configuración en Android

### 1. `AndroidManifest.xml`
Ya configurado:
```xml
<uses-permission android:name="android.permission.INTERNET" />

<application
    android:networkSecurityConfig="@xml/network_security_config"
    android:usesCleartextTraffic="true"
    ...>
```

### 2. `network_security_config.xml`
Ya configurado para permitir tráfico HTTP en desarrollo:
```xml
<network-security-config>
    <domain-config cleartextTrafficPermitted="true">
        <domain includeSubdomains="true">10.0.2.2</domain>
        <domain includeSubdomains="true">192.168.0.0/16</domain>
    </domain-config>
</network-security-config>
```

### 3. Retrofit Setup
Ya configurado en `ChatApiServiceBaseDeDatos.kt`:
```kotlin
private const val BASE_URL = "http://10.0.2.2:8000/"

fun create(): ChatApiServiceBaseDeDatos {
    return Retrofit.Builder()
        .baseUrl(BASE_URL)
        .addConverterFactory(GsonConverterFactory.create())
        .build()
        .create(ChatApiServiceBaseDeDatos::class.java)
}
```

**Para cambiar la URL (dispositivo físico):**
```kotlin
private const val BASE_URL = "http://192.168.1.100:8000/"
```

### 4. Firebase SDK
Agregar a `app/build.gradle.kts`:
```kotlin
dependencies {
    // Firebase
    implementation(platform("com.google.firebase:firebase-bom:32.7.0"))
    implementation("com.google.firebase:firebase-auth")
    implementation("com.google.firebase:firebase-firestore")
}
```

Y colocar `google-services.json` en `app/` (descargar desde Firebase Console).

## Testing

### 1. Verificar que la API está corriendo
```bash
# En la PC
curl http://localhost:8000/api/v1/health
```

Debería devolver:
```json
{
  "status": "healthy",
  "version": "1.0.0",
  "model_loaded": true,
  "timestamp": "..."
}
```

### 2. Probar desde el emulador Android
```kotlin
// En MainActivity.kt o donde corresponda
val client = OkHttpClient()
val request = Request.Builder()
    .url("http://10.0.2.2:8000/api/v1/health")
    .build()

client.newCall(request).enqueue(object : Callback {
    override fun onResponse(call: Call, response: Response) {
        Log.d("API", "Response: ${response.body?.string()}")
    }
    
    override fun onFailure(call: Call, e: IOException) {
        Log.e("API", "Error: ${e.message}")
    }
})
```

### 3. Probar el chatbot
```bash
curl -X POST http://localhost:8000/api/v1/chat \
  -H "Content-Type: application/json" \
  -d '{
    "message": "¿Cómo está el sistema?",
    "silo_id": "SILO_001",
    "session_id": "test"
  }'
```

## Troubleshooting

### ❌ "Network error" en la app
- Verificar que la API está corriendo: `curl http://localhost:8000/api/v1/health`
- Verificar que `network_security_config.xml` permite `10.0.2.2`
- Si usás dispositivo físico, cambiar `10.0.2.2` por la IP de tu PC

### ❌ "Firebase not initialized"
- Verificar que `firebase/serviceAccountKey.json` existe en `Inteligencia_Artificial/`
- Verificar que las credenciales de Firebase en `.env` son correctas

### ❌ "Chatbot no responde"
- Verificar que `GROQ_API_KEY` está configurada en `Inteligencia_Artificial/.env`
- Verificar que la AI API está corriendo y el modelo está cargado

### ❌ "No se pueden crear usuarios"
- Verificar que Firebase Auth está habilitado en Firebase Console
- Verificar que el método de autenticación "Email/Password" está activado

## Próximos Pasos

1. **Agregar Firebase SDK a la app** (actualmente no está en las dependencias)
2. **Implementar login screen** en la app (actualmente no hay UI de login)
3. **Sincronización en tiempo real** con Firestore listeners
4. **Notificaciones push** con Firebase Cloud Messaging (FCM)
5. **Offline support** con Firestore persistence

---

**Última actualización:** 2026-01-15

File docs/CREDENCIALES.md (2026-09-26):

# 🔑 ¿De dónde sale cada credencial?

Guía rápida: qué es cada valor, en qué consola se obtiene y dónde va.

---

## 1. TTN (The Things Network) → `Backend_Arduino/.env`

Consola: <https://console.cloud.thethings.network> → elegir cluster
(por defecto **Europe 1**; si la app está en Australia, elegir ese cluster).

| Variable | De dónde sale | Cómo |
|---|---|---|
| `TTN_APP_ID` | Applications → tu aplicación → **General information → Application ID** | Copiar tal cual (ej: `agrilion`) |
| `TTN_USER` | Es el Application ID + `@ttn` | Ej: `agrilion@ttn` |
| `TTN_PASS` | Applications → tu app → **API keys → Add API key** | Nombre: `agrilion-mqtt`, Rights: **Read application traffic**. Copiar la key (empieza con `NNSXS.`) — **se muestra una sola vez** |
| `TTN_BROKER` | Según el cluster elegido arriba | Europe 1: `eu1.cloud.thethings.network` · North America: `nam1.cloud.thethings.network` · Australia: `au1.cloud.thethings.network` |
| `TTN_PORT` | Puerto TLS de TTN | **`8883`** (el 1883 fue cerrado por TTN: corta la conexión) |

> La API key tiene que crearse **dentro de la aplicación** (Applications → tu app
> → API keys). Si se crea en "Personal API keys" (nivel usuario), el MQTT
> responde **Not authorized**.
>
> El AppKey del firmware (OTAA) se rota aparte: ver
> [`ROTACION_CREDENCIALES.md`](./ROTACION_CREDENCIALES.md).

---

## 2. HiveMQ Cloud → `Backend_Arduino/.env`

Consola: <https://console.hivemq.cloud>

| Variable | De dónde sale | Cómo |
|---|---|---|
| `HIVEMQ_BROKER` | Clusters → tu cluster → **Overview / Details → Cluster URL** | Ej: `abc123.s1.eu.hivemq.cloud` (sin `mqtt://` ni puerto) |
| `HIVEMQ_PORT` | Puerto TLS estándar | `8883` |
| `HIVEMQ_USER` | Cluster → **Access Management → Credentials** | Crear/ver usuario (ej: `agrilion`) |
| `HIVEMQ_PASS` | Igual que arriba | La contraseña del usuario. Si no la recordás, crear una credencial nueva |

---

## 3. InfluxDB → `Backend_Arduino/.env` e `Inteligencia_Artificial/.env`

**Local (Docker, ya configurado por nosotros):**

| Variable | Valor |
|---|---|
| `INFLUX_URL` / `INFLUX_HOST` | `http://localhost:8181` |
| `INFLUX_DATABASE` / `INFLUX_BUCKET` | `silobolsas` |
| `INFLUX_TOKEN` | Ya cargado en los `.env` (token admin generado en el contenedor) |

Si algún día se usa InfluxDB Cloud 3: Cloud → **Load Data → API Tokens** → copiar
el token y la URL de la instancia.

---

## 4. Firebase → web + backends

Consola: <https://console.firebase.google.com>

### 4.1 Config web → `paginaweb/.env.local`

**Configuración del proyecto (⚙️) → General → Tus apps → Web (`</>`)** →
si no hay app web, crearla → sección **SDK setup and configuration → Config**.
De ese objeto `firebaseConfig` salen:

| `.env.local` | `firebaseConfig` |
|---|---|
| `NEXT_PUBLIC_FIREBASE_API_KEY` | `apiKey` |
| `NEXT_PUBLIC_FIREBASE_AUTH_DOMAIN` | `authDomain` |
| `NEXT_PUBLIC_FIREBASE_PROJECT_ID` | `projectId` |
| `NEXT_PUBLIC_FIREBASE_STORAGE_BUCKET` | `storageBucket` |
| `NEXT_PUBLIC_FIREBASE_MESSAGING_SENDER_ID` | `messagingSenderId` |
| `NEXT_PUBLIC_FIREBASE_APP_ID` | `appId` |

### 4.2 Clave de administrador → backends

**Configuración del proyecto → Cuentas de servicio → Firebase Admin SDK →
Generar nueva clave privada** → descargar el JSON → guardarlo como
`serviceAccountKey.json` en **las dos** carpetas:

```
Backend_Arduino/firebase/serviceAccountKey.json
Inteligencia_Artificial/firebase/serviceAccountKey.json
```

### 4.3 Android → `AppCelular/app/`

**Configuración del proyecto → General → Tus apps → Android** →
registrar `com.example.app1` → descargar `google-services.json` → guardarlo en
`AppCelular/app/google-services.json`.

---

## 5. Verificación final

```bash
python scripts/check_env.py      # TTN, HiveMQ, Influx, web
python scripts/check_mqtt.py     # conexión y auth MQTT (TTN + HiveMQ)
python scripts/check_firebase.py # serviceAccountKey + Auth + Firestore
python scripts/check_influx.py   # Influx local
python scripts/e2e_simulation.py # simulación completa sin hardware
```

Guía completa de Firebase: [`FIREBASE_SETUP.md`](./FIREBASE_SETUP.md).

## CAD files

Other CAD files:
ModelosPlaquetas_Lanza/ESTACA BOCETO (PUNTA DE LANZA) f.f3d

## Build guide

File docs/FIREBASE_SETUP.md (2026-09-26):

# 🔥 Firebase — Guía de configuración de Agrilion

Esta guía deja Firebase listo para:
- Registro/login real en la web (`paginaweb`) con email/contraseña y Google.
- Perfil y silobolsas en Firestore (`users/{uid}/silos/{silo_id}`).
- Registro global de sensores (`sensors/{device_id}`) que usa el backend MQTT.
- App Android (`AppCelular`) contra el mismo proyecto.

> Proyecto sugerido: **agrilion-app** (o el nombre que prefieras).
> Dueño: `manuysys@gmail.com`. Podés invitar a `eest4.74.agrilion@gmail.com`
> como **Editor** (Configuración del proyecto → Usuarios y permisos → Agregar miembro).

---

## 1. Crear el proyecto

1. Ir a <https://console.firebase.google.com/>
2. **Agregar proyecto** → nombre `agrilion-app` → Continuar.
3. Google Analytics: se puede desactivar (no se usa).
4. Crear proyecto.

## 2. Activar Authentication

1. Menú lateral → **Compilación → Authentication** → Comenzar.
2. Pestaña **Sign-in method**:
   - **Correo electrónico/contraseña** → Habilitar.
   - **Google** → Habilitar → elegir correo de soporte del proyecto.
3. Pestaña **Settings → Authorized domains**: `localhost` ya está. Agregar el
   dominio cuando se despliegue la web (ej: `project-rprtv.vercel.app`).

## 3. Crear Firestore

1. Menú lateral → **Compilación → Firestore Database** → Crear base de datos.
2. Modo: **Producción**.
3. Ubicación: `southamerica-east1` (São Paulo) o `us-east1`.
4. Una vez creada, ir a la pestaña **Rules** y pegar las reglas del punto 7.

## 4. Registrar la app Web

1. **Configuración del proyecto** (⚙️) → **General** → *Tus apps* →
   **Web** (`</>`).
2. Apodo: `agrilion-web`. No hace falta Firebase Hosting.
3. Copiar el objeto `firebaseConfig` a `paginaweb/.env.local`:

```env
NEXT_PUBLIC_FIREBASE_API_KEY=...
NEXT_PUBLIC_FIREBASE_AUTH_DOMAIN=agrilion-app.firebaseapp.com
NEXT_PUBLIC_FIREBASE_PROJECT_ID=agrilion-app
NEXT_PUBLIC_FIREBASE_STORAGE_BUCKET=agrilion-app.appspot.com
NEXT_PUBLIC_FIREBASE_MESSAGING_SENDER_ID=...
NEXT_PUBLIC_FIREBASE_APP_ID=...
```

4. Reiniciar el frontend (`npm run dev`).

## 5. Service Account (backend + IA)

1. **Configuración del proyecto** → **Cuentas de servicio** →
   **Generar nueva clave privada** → descargar el JSON.
2. Renombrarlo a `serviceAccountKey.json` y guardarlo en **ambas** carpetas:

```
Backend_Arduino/firebase/serviceAccountKey.json
Inteligencia_Artificial/firebase/serviceAccountKey.json
```

> ⚠️ Nunca commitear este archivo (ya está en `.gitignore`).

3. Verificar:

```bash
python scripts/check_firebase.py
```

## 6. App Android

1. **Configuración del proyecto** → *Tus apps* → **Android**.
2. Nombre de paquete: `com.example.app1` (el que usa `AppCelular`).
3. Descargar `google-services.json` → guardarlo en:

```
AppCelular/app/google-services.json
```

4. La app ya trae Firebase Auth + Firestore en `AuthManager.kt`
   (ver `MOBILE_INTEGRATION.md`).

## 7. Reglas de Firestore

Pegar en **Firestore → Rules → Publicar**:

```javascript
rules_version = '2';
service cloud.firestore {
  match /databases/{database}/documents {

    // Cada usuario administra su perfil y sus silos
    match /users/{userId} {
      allow read, write: if request.auth != null && request.auth.uid == userId;

      match /silos/{siloId} {
        allow read, write: if request.auth.uid == userId;

        match /sensors/{sensorId} {
          allow read, write: if request.auth.uid == userId;
        }
      }

      match /alerts/{alertId} {
        allow read, write: if request.auth.uid == userId;
      }
    }

    // Lookup global de sensores: lectura autenticada, escritura solo backend
    match /sensors/{deviceId} {
      allow read: if request.auth != null;
      allow write: if false;
    }
  }
}
```

## 8. Probar el flujo completo

1. `python scripts/check_firebase.py` → debe decir **Firebase listo**.
2. Levantar la AI API (`uvicorn api.app:app --port 8000` en
   `Inteligencia_Artificial/`).
3. Levantar la web (`npm run dev` en `paginaweb/`).
4. Ir a `http://localhost:3000/registro`, crear la cuenta con el Gmail del
   proyecto (ej: `eest4.74.agrilion@gmail.com`).
5. Ir a **Dashboard → Configuración → Registrar lanza / silobolsa de prueba**:
   - Nombre: `Lanza de prueba`
   - Grano: soja
   - Device ID de TTN: `smisia-cubecellab02s`
   - **Crear y asociar sensor**
6. Verificar en la consola de Firebase:
   - `users/{uid}` con email/nombre.
   - `users/{uid}/silos/SB-xxxxx` con `grainType`.
   - `sensors/smisia-cubecellab02s` con `ownerUid` y `siloId`.

Con eso, cuando la lanza empiece a transmitir, el backend va a escribir:
- **InfluxDB**: measurement `sensores` (temperatura, humedad, co2, score...).
- **Firestore**: `sensor.lastSeen` y `users/{uid}/silos/{silo}.estado/score/alerta`.

## 9. Errores comunes

| Error | Causa | Solución |
|---|---|---|
| `auth/operation-not-allowed` | Email/Password deshabilitado | Activarlo en Authentication → Sign-in method |
| `auth/unauthorized-domain` | Dominio no autorizado | Agregar el dominio en Authentication → Settings |
| `Missing or insufficient permissions` | Reglas de Firestore | Publicar las reglas del punto 7 |
| `Firebase no disponible` en AI API | Falta `serviceAccountKey.json` | Punto 5 |
| `AI API 503: Firebase no disponible` | Igual que arriba | Punto 5 |

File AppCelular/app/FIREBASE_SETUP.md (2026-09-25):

# Firebase Configuration — Agrilion Android App

## ⚠️ Configuración requerida

Para que la app pueda usar Firebase Auth y Firestore, necesitás agregar el archivo
`google-services.json` en esta carpeta (`AppCelular/app/`).

## Pasos para obtener `google-services.json`

### 1. Ir a Firebase Console
- Abrir: https://console.firebase.google.com/
- Ingresar con tu cuenta de Google
- Seleccionar o crear el proyecto **AGRILION**

### 2. Agregar app Android al proyecto
1. Click en el ícono de **Android** (Agregar app)
2. **Nombre del paquete Android**: `com.example.app1`
3. **Nombre del apodo**: `Agrilion` (opcional)
4. **Certificado SHA-1**: Para desarrollo se puede dejar vacío. Para producción, obtenerlo con:
   ```bash
   keytool -list -v -keystore ~/.android/debug.keystore -alias androiddebugkey -storepass android -keypass android
   ```

### 3. Descargar el archivo
1. Click en **Descargar google-services.json**
2. Mover el archivo a esta ubicación exacta:
   ```
   AppCelular/app/google-services.json
   ```

### 4. Verificar configuración
- Sincronizar Gradle en Android Studio: `File → Sync Project with Gradle Files`
- No debe haber errores de build

## ⚠️ Importante

- `google-services.json` **NO debe subirse a git** (ya está en `.gitignore`)
- Cada desarrollador debe descargar su propio archivo
- En CI/CD (producción), se puede guardar como variable secreta o en Secret Manager

## Features habilitadas con Firebase

Una vez configurado, la app tendrá:

| Feature | Descripción |
|---|---|
| **Auth** | Login/registro con email+password, Google Sign-In (futuro) |
| **Firestore** | Sincronización en tiempo real de silos, sensores y alertas |
| **Analytics** | Métricas de uso (opcional) |

## Estructura de datos en Firestore

```
users/{uid}/
  ├── email, name, phone, company
  └── silos/{siloId}/
        ├── name, grainType, location, tons
        └── sensors/{deviceId}/
              ├── active, battery, lastSeen
```

## Verificar que funciona

En la app, abrir `LoginScreen`. Si Firebase está bien configurado,
podrás registrar un usuario nuevo y loguearte.

Si ves errores del tipo `API key not valid`, el problema está en `google-services.json`.

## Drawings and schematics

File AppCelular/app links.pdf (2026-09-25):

## DASHBOARD

## Pantalla Principal

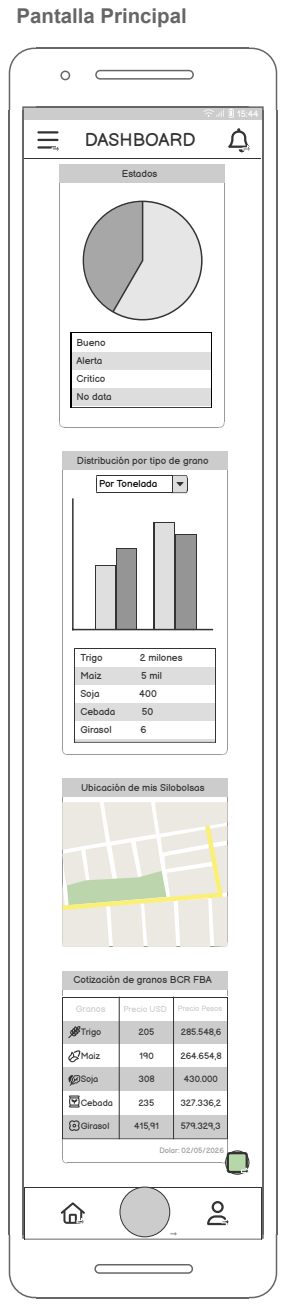
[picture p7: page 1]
Bueno; Alerta; Critico; No data; Estados; Por Tonelada; Trigo; 2 milones; Maiz; 5 mil; Soja; Cebada; Girasol; Granos; Precio USD; Precio Pesos; Dolar: 02/05/2026

Distribución por tipo de grano

Ubicación de mis Silobolsas

Cotización de granos BCR FBA

15:44

# NOTIFICACIONES

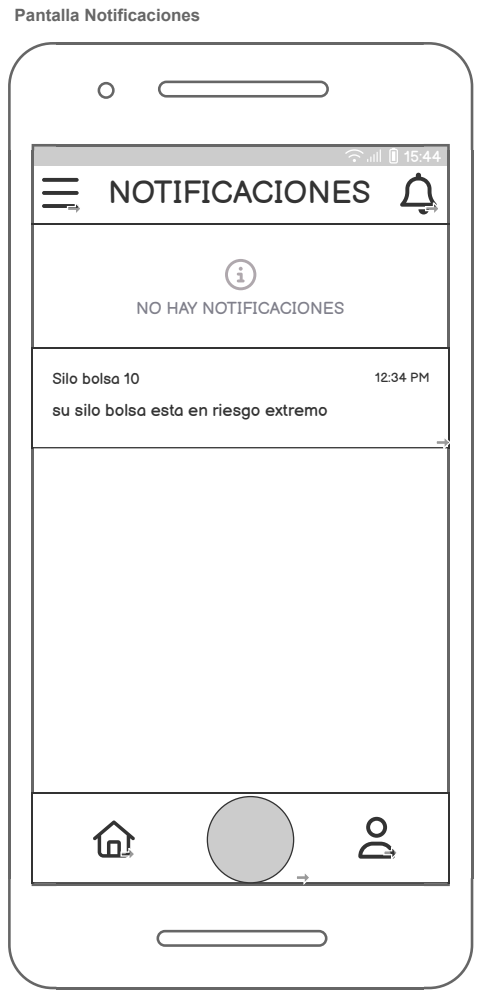
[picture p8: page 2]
Pantalla Notificaciones

NO HAY NOTIFICACIONES

Silo bolsa 10
su silo bolsa esta en riesgo extremo

15:44

# DASHBOARD

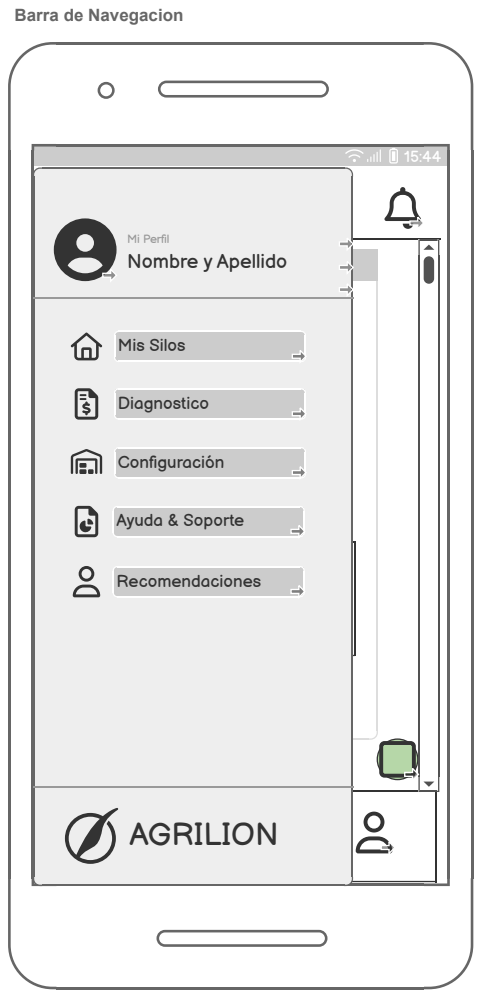
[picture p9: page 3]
Item One; Item Two; Item Three; Estados; Mis Silos; Diagnostico; Configuración; Ayuda & Soporte; Recomendaciones; Nombre y Apellido; Mi Perfil; AGRILION

Barra de Navegacion

15:44

## RECOMENDACIONES

Este mes sus condiciones ambientales fueron excelentes, a este paso el valor de sus semillas se mantendrá estable en el mercado. Se recomienda vender sus bolsas antes que la primavera llegue y se pierda la viabilidad de las condiciones ambientales de su silobolsa.

## Trigo

Este mes sus condiciones ambientales se deterioraron gradualmente, a este paso el valor de sus semillas se perderá en el mercado. Se recomienda revisar su silobolsa/s X, XX y XXX para sellar su rotura/ forzar la aireación de su silobolsa; para detener el crecimiento de hongos e insectos, y evitar que se pierda el valor en el mercado.

## Maiz

Este mes sus condiciones ambientales deterioraron por completo su semilla, eliminando su valor en el mercado. Se recomienda realizar un examen de micotoxina a X, XX y XXX bolsa antes de que sus condiciones ambientales afecten la sanidad del resto del lote, permitiendo diferenciar las semillas sanas de las que deben estar bajo observación y las perdidas totales. También es recomendable vender las semillas lo antes posible para recuperar su inversión, las semillas en observación mantenerlas en una bolsa aparte para su debido mantenimiento y venderlas antes del primer mes para evitar que su precio en el mercado caiga completamente y las semillas perdidas desecharlas.

## Soja

Este mes no se presentaron datos de sus condiciones ambientales, revisa las bolsas sin datos y llama al servicio técnico para una evaluación profesional. Se recomienda actuar lo antes posible para evitar perdidas irreversibles del producto.

## Cebada

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

## Girasol

## Recomendaciones

15:44

# AYUDA & SOPORTE

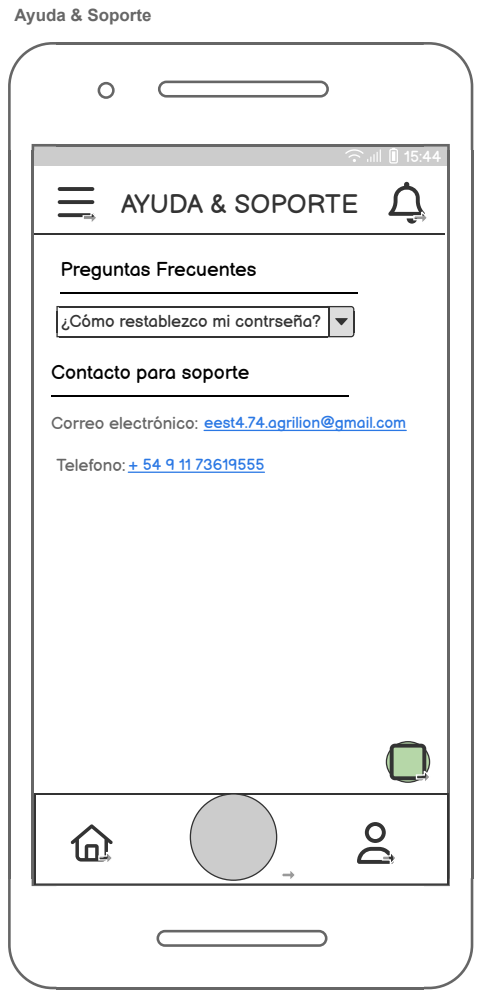
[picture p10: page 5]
Preguntas Frecuentes; Telefono: + 54 9 11 73619555; Ayuda & Soporte

¿Cómo restablezco mi contrseña?

Contacto para soporte

Correo electrónico: eest4.74.agrilion@gmail.com

# CONFIGURACION

# Idioma

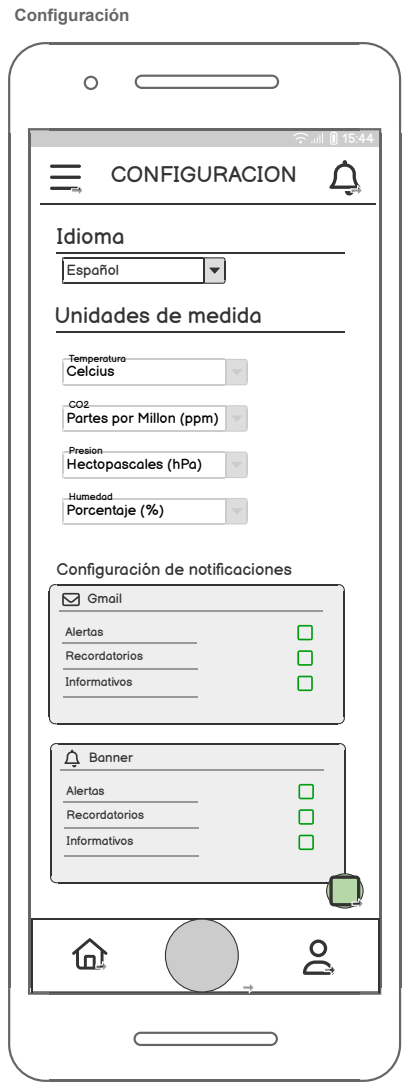
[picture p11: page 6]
Hectopascales (hPa); Celcius; Temperatura; Presion; Gmail; Alertas; Recordatorios; Informativos; Banner; Porcentaje (%); Humedad; Configuración

Español
Unidades de medida

Partes por Millon (ppm)

Configuración de notificaciones

## Diagnostico

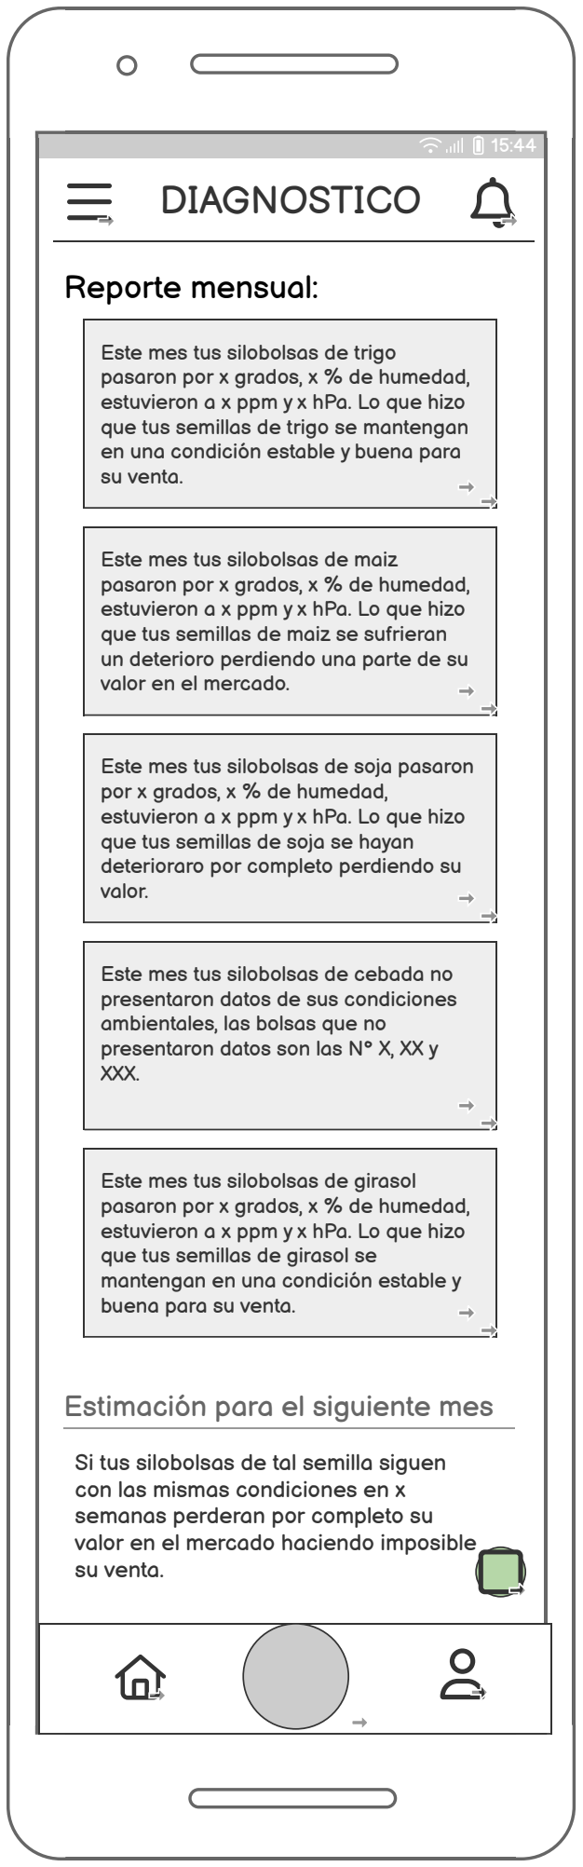
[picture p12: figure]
DIAGNOSTICO; Este mes tus silobolsas de trigo pasaron por x grados, x % de humedad, estuvieron a x ppm y x hPa. Lo que hizo que tus semillas de trigo se mantengan en una condición estable y buena para su venta.; Este mes tus silobolsas de maiz pasaron por x grados, x % de humedad, estuvieron a x ppm y x hPa. Lo que hizo que tus semillas de maiz se sufrieran un deterioro perdiendo una parte de su valor en el mercado.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

15:44

# MIS SILOS

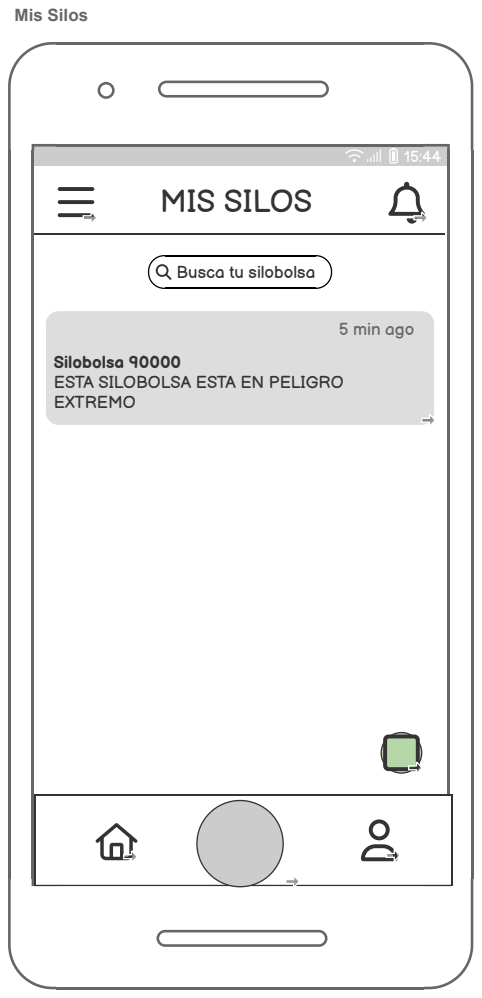
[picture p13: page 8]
5 min ago; Mis Silos

Busca tu silobolsa

Silobolsa 90000
ESTA SILOBOLSA ESTA EN PELIGRO
EXTREMO

## SILOBOLSAS

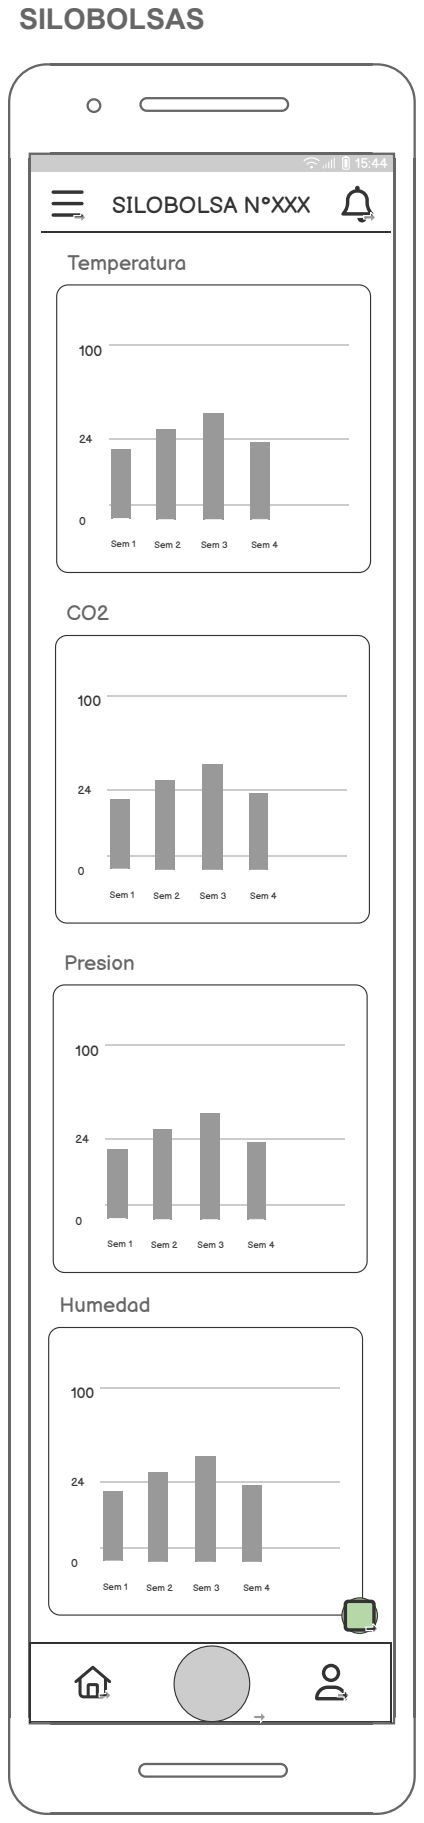
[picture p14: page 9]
SILOBOLSA N°XXX; Sem 1; Sem 2; Sem 3; Sem 4; Temperatura; Presion; Humedad

15:44

# LION

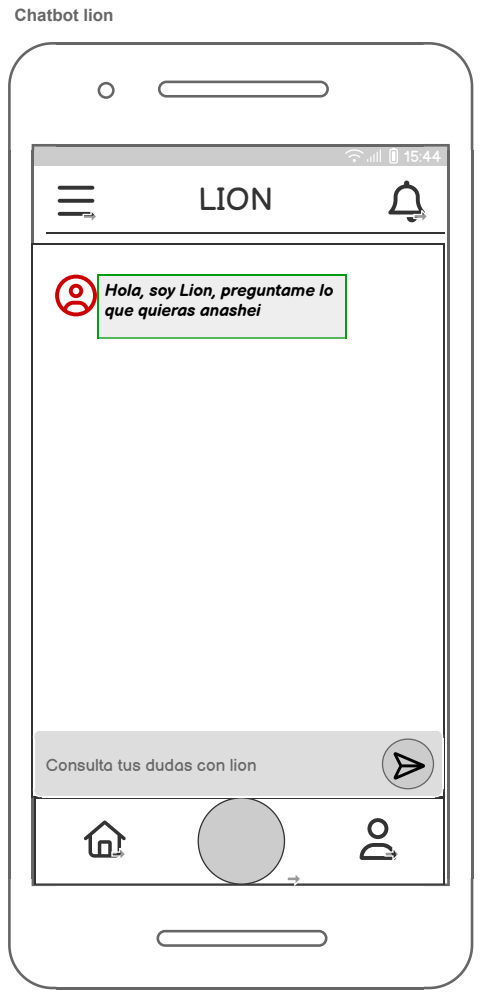
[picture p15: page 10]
Chatbot lion

Hola, soy Lion, preguntame lo
que quieras anashei

Consulta tus dudas con lion

15:44

# MI PERFIL

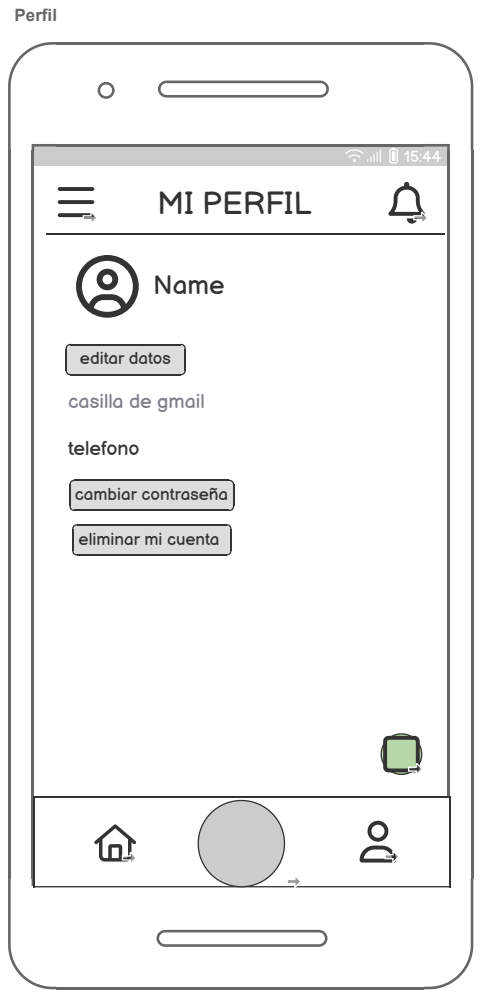
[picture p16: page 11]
Name; telefono; cambiar contraseña; Perfil

editar datos
casilla de gmail

eliminar mi cuenta

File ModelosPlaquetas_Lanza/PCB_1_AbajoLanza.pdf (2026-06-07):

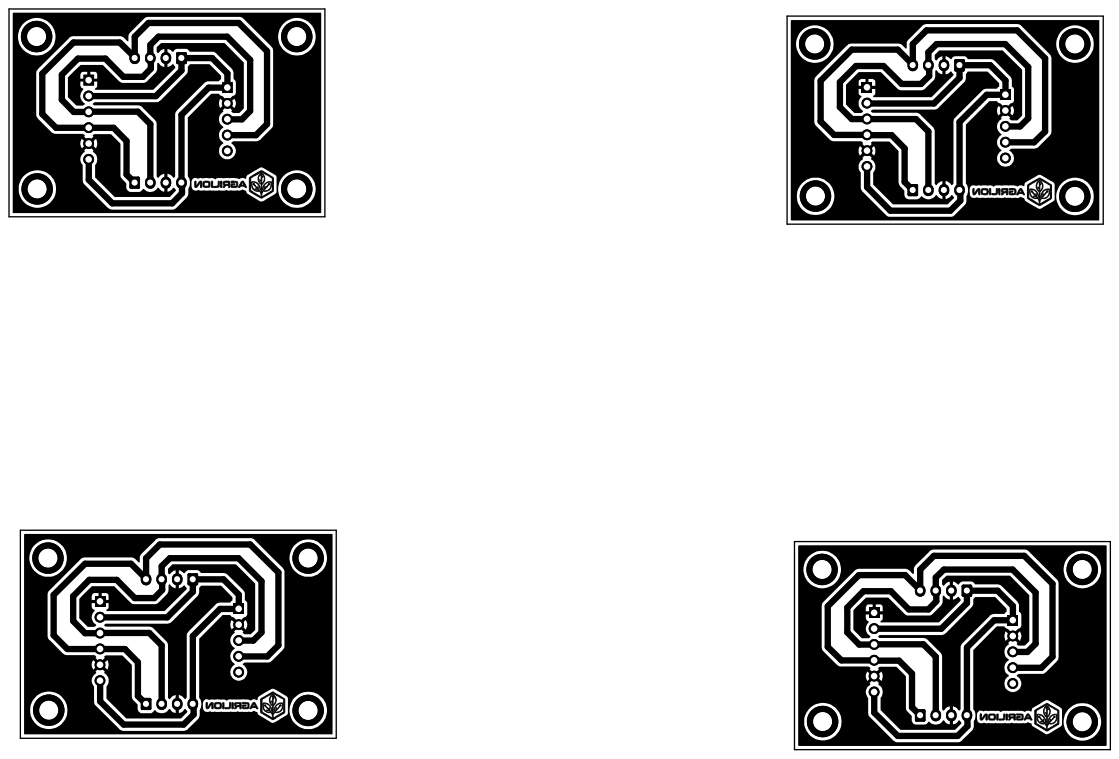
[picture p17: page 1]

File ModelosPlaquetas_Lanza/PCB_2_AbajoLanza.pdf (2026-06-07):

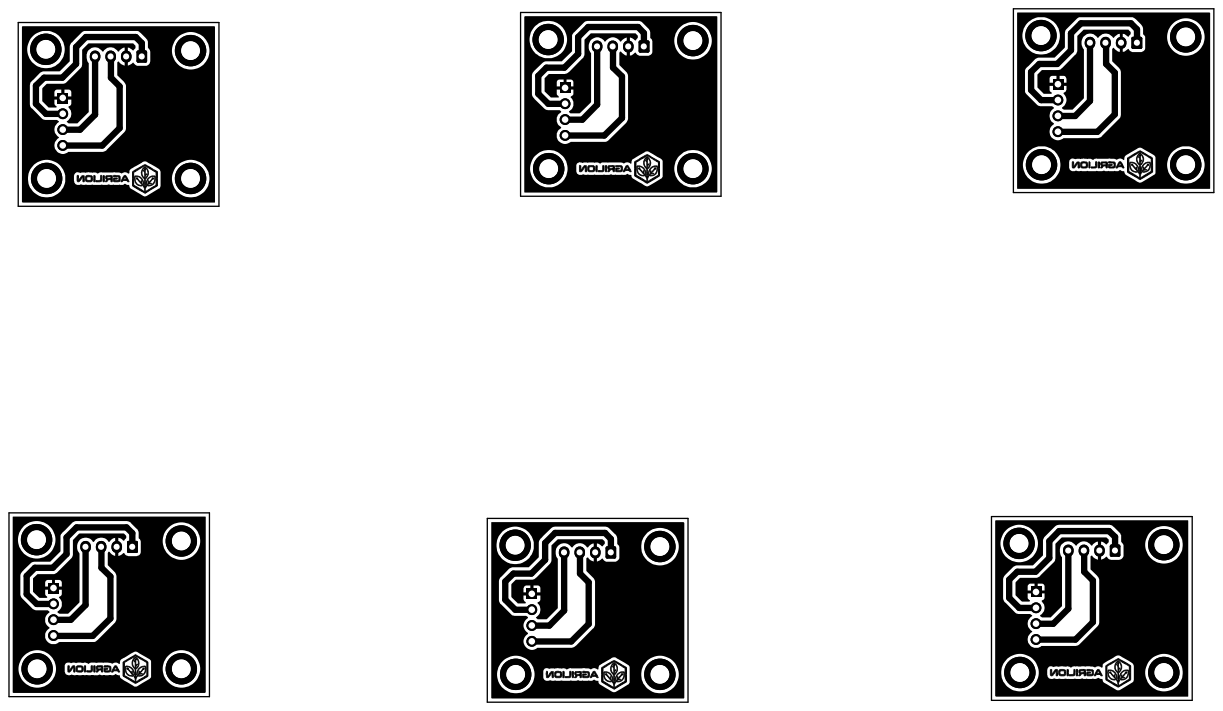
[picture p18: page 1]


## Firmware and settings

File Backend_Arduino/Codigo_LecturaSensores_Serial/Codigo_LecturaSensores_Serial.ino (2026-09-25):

// ============================================================
// Código de Lectura de Sensores — Solo Serial Monitor
// Basado en: Codigo_TransmisionLoraWAN_Sensores.ino
// Sin LoRaWAN: solo lee y muestra datos por Serial.
// Sensores: BME280 + SHT30 + SCD41 + ADXL345
// ============================================================

#include "Arduino.h"
#include <Wire.h>
#include <Adafruit_Sensor.h>
#include <Adafruit_BME280.h>
#include <Adafruit_SHT31.h>
#include <SparkFun_SCD4x_Arduino_Library.h>
#include <Adafruit_ADXL345_U.h>

// ================== Sensores ==================
Adafruit_BME280 bme;
Adafruit_SHT31  sht30 = Adafruit_SHT31();
SCD4x           scd41;
Adafruit_ADXL345_Unified accel = Adafruit_ADXL345_Unified(12345);

// ================== Flags de sensores detectados ==================
bool bme_ok   = false;
bool sht_ok   = false;
bool scd_ok   = false;
bool adxl_ok  = false;

// ================== Interrupción ADXL345 ==================
#define PIN_INTERRUPCION GPIO5

volatile bool flag_interrupcion  = false;
bool     impactoPendiente        = false;
uint16_t aceleracionGuardada     = 0;

// ================== Intervalo de lectura ==================
unsigned long tiempoAnterior = 0;
const unsigned long INTERVALO_LECTURA = 5000; // 5 segundos
uint32_t numeroLectura = 0;

// ================== CONFIGURAR ADXL345 ==================
void configurarADXL345()
{
  if (!accel.begin())
  {
    Serial.println("  ❌ ADXL345 no detectado.");
    adxl_ok = false;
    return;
  }

  adxl_ok = true;
  Serial.println("  ✅ ADXL345 detectado.");

  accel.setRange(ADXL345_RANGE_16_G);

  // THRESH_ACT: umbral de actividad
  Wire.beginTransmission(0x53);
  Wire.write(0x24); Wire.write(10);
  Wire.endTransmission();

  // ACT_INACT_CTL: habilitar detección AC en X, Y, Z
  Wire.beginTransmission(0x53);
  Wire.write(0x27); Wire.write(0x70);
  Wire.endTransmission();

  // INT_ENABLE: Activity es bit 4 = 0x10
  // NOTA: En el código LoRaWAN original estaba 0x01 (DATA_READY),
  // lo cual generaría falsos disparos. Aquí se corrige a 0x10.
  Wire.beginTransmission(0x53);
  Wire.write(0x2E); Wire.write(0x10); // ← CORREGIDO: bit 4 = Activity
  Wire.endTransmission();

  // INT_MAP: Activity → INT1 (pin)
  Wire.beginTransmission(0x53);
  Wire.write(0x2F); Wire.write(0x00);
  Wire.endTransmission();

  delay(50);

  // Limpiar cualquier interrupción pendiente al inicio
  Wire.beginTransmission(0x53);
  Wire.write(0x30);
  Wire.endTransmission(false);
  Wire.requestFrom((uint8_t)0x53, (uint8_t)1);
  if (Wire.available()) Wire.read();
}

// ================== LEER ACELERACIÓN ==================
float leerAcelerometroInstantaneo()
{
  if (!adxl_ok) return 0.0;

  sensors_event_t event;
  accel.getEvent(&event);

  float ax = event.acceleration.x;
  float ay = event.acceleration.y;
  float az = event.acceleration.z;
  float magnitud = sqrt(ax * ax + ay * ay + az * az);

  // Limpiar flag de interrupción del ADXL345
  Wire.beginTransmission(0x53);
  Wire.write(0x30);
  Wire.endTransmission(false);
  Wire.requestFrom((uint8_t)0x53, (uint8_t)1);
  if (Wire.available()) Wire.read();

  return abs(magnitud - 9.81);
}

// ================== INTERRUPCIÓN ==================
void ISR_Movimiento()
{
  flag_interrupcion = true;
}

// ================== SETUP ==================
void setup()
{
  Serial.begin(115200);
  delay(2000); // Esperar a que abra el Serial Monitor

  Serial.println();
  Serial.println("============================================");
  Serial.println("  AGRILION — Lectura de Sensores (Serial)");
  Serial.println("  BME280 + SHT30 + SCD41 + ADXL345");
  Serial.println("============================================");
  Serial.println();

  // Encender Vext para alimentar sensores I2C
  pinMode(Vext, OUTPUT);
  digitalWrite(Vext, LOW);
  delay(3000); // Estabilización de energía

  // Iniciar bus I2C
  Wire.begin();
  Wire.setClock(50000);

  // --- Inicializar BME280 ---
  Serial.println("Inicializando sensores...");
  if (bme.begin(0x76)) {
    bme_ok = true;
    Serial.println("  ✅ BME280 detectado en 0x76.");
  } else if (bme.begin(0x77)) {
    bme_ok = true;
    Serial.println("  ✅ BME280 detectado en 0x77.");
  } else {
    Serial.println("  ❌ BME280 no detectado.");
  }

  // --- Inicializar SHT30 ---
  if (sht30.begin(0x44)) {
    sht_ok = true;
    Serial.println("  ✅ SHT30 detectado en 0x44.");
  } else {
    Serial.println("  ❌ SHT30 no detectado.");
  }

  // --- Inicializar SCD41 ---
  if (scd41.begin(Wire)) {
    scd_ok = true;
    Serial.println("  ✅ SCD41 detectado.");
  } else {
    Serial.println("  ❌ SCD41 no detectado.");
  }
  delay(600);

  // --- Inicializar ADXL345 ---
  configurarADXL345();

  // --- Configurar interrupción ---
  if (adxl_ok) {
    pinMode(PIN_INTERRUPCION, INPUT_PULLDOWN);
    attachInterrupt(digitalPinToInterrupt(PIN_INTERRUPCION), ISR_Movimiento, RISING);
  }

  Serial.println();
  Serial.println("============================================");
  Serial.print("  Sensores activos: ");
  int count = 0;
  if (bme_ok)  count++;
  if (sht_ok)  count++;
  if (scd_ok)  count++;
  if (adxl_ok) count++;
  Serial.print(count);
  Serial.println("/4");
  Serial.print("  Intervalo de lectura: ");
  Serial.print(INTERVALO_LECTURA / 1000);
  Serial.println(" segundos");
  Serial.println("============================================");
  Serial.println();
}

// ================== LOOP ==================
void loop()
{
  // --- Detectar impacto por interrupción ---
  if (flag_interrupcion)
  {
    flag_interrupcion = false;
    float valorImpacto  = leerAcelerometroInstantaneo();
    aceleracionGuardada = (uint16_t)(valorImpacto * 10);
    impactoPendiente    = true;

    Serial.println();
    Serial.println("🚨🚨🚨 ¡IMPACTO DETECTADO! 🚨🚨🚨");
    Serial.print("  Aceleración neta: ");
    Serial.print(valorImpacto, 2);
    Serial.println(" m/s²");
    Serial.println();
  }

  // --- Lectura periódica de sensores ---
  unsigned long tiempoActual = millis();

  if (tiempoActual - tiempoAnterior >= INTERVALO_LECTURA)
  {
    tiempoAnterior = tiempoActual;
    numeroLectura++;

    Wire.setClock(50000);

    Serial.println("────────────────────────────────────────");
    Serial.print("  Lectura #");
    Serial.print(numeroLectura);
    Serial.print("  |  Uptime: ");
    Serial.print(tiempoActual / 1000);
    Serial.println("s");
    Serial.println("────────────────────────────────────────");

    // ---- SHT30: Temperatura y Humedad ----
    Serial.println("  [ SHT30 ]");
    if (sht_ok) {
      float temp_sht = sht30.readTemperature();
      float hum_sht  = sht30.readHumidity();

      if (!isnan(temp_sht)) {
        Serial.print("    Temperatura: ");
        Serial.print(temp_sht, 2);
        Serial.println(" °C");
      } else {
        Serial.println("    Temperatura: ERROR de lectura");
      }

      if (!isnan(hum_sht)) {
        Serial.print("    Humedad:     ");
        Serial.print(hum_sht, 2);
        Serial.println(" %");
      } else {
        Serial.println("    Humedad:     ERROR de lectura");
      }
    } else {
      Serial.println("    (no conectado)");
    }

    // ---- BME280: Presión (+ temp/hum de respaldo) ----
    Serial.println("  [ BME280 ]");
    if (bme_ok) {
      float temp_bme = bme.readTemperature();
      float hum_bme  = bme.readHumidity();
      float pres_bme = bme.readPressure() / 100.0F;

      Serial.print("    Presión:     ");
      Serial.print(pres_bme, 1);
      Serial.println(" hPa");
      Serial.print("    Temp (ref):  ");
      Serial.print(temp_bme, 2);
      Serial.println(" °C");
      Serial.print("    Hum  (ref):  ");
      Serial.print(hum_bme, 2);
      Serial.println(" %");
    } else {
      Serial.println("    (no conectado)");
    }

    // ---- SCD41: CO2 ----
    Serial.println("  [ SCD41 ]");
    if (scd_ok) {
      uint16_t co2 = 0;
      scd41.measureSingleShot();

      bool medicionLista = false;
      for (int i = 0; i < 13; i++) {
        delay(500);
        // NOTA: readMeasurement() retorna false cuando la lectura es EXITOSA
        // (true = error CRC / fallo comunicación). Corregido respecto al original.
        if (scd41.readMeasurement() == false) {
          co2 = scd41.getCO2();
          medicionLista = true;
          break;
        }
      }

      if (medicionLista && co2 > 0) {
        Serial.print("    CO2:         ");
        Serial.print(co2);
        Serial.println(" ppm");

        // Contexto del valor
        if (co2 < 400) {
          Serial.println("    Estado:      ⬇️ Bajo (exterior o ventilado)");
        } else if (co2 < 1000) {
          Serial.println("    Estado:      ✅ Normal");
        } else if (co2 < 2000) {
          Serial.println("    Estado:      ⚠️ Elevado — revisar");
        } else {
          Serial.println("    Estado:      🚨 CRÍTICO — posible fermentación");
        }
      } else {
        Serial.println("    CO2:         Sin datos (timeout 6.5s)");
      }
    } else {
      Serial.println("    (no conectado)");
    }

    // ---- ADXL345: Acelerómetro ----
    Serial.println("  [ ADXL345 ]");
    if (adxl_ok) {
      float accelVal = leerAcelerometroInstantaneo();
      Serial.print("    Acel. neta:  ");
      Serial.print(accelVal, 2);
      Serial.println(" m/s²");

      if (impactoPendiente) {
        Serial.print("    ⚡ Impacto pendiente: ");
        Serial.print(aceleracionGuardada / 10.0, 1);
        Serial.println(" m/s²");
        impactoPendiente = false;
        aceleracionGuardada = 0;
      }
    } else {
      Serial.println("    (no conectado)");
    }

    // ---- Resumen compacto (fácil de copiar) ----
    Serial.println("  ─ ─ ─ ─ ─ ─ ─ ─ ─ ─ ─ ─ ─ ─ ─ ─ ─ ─");
    Serial.print("  CSV: ");
    Serial.print(tiempoActual / 1000); Serial.print(",");

    if (sht_ok) {
      float t = sht30.readTemperature();
      float h = sht30.readHumidity();
      Serial.print(isnan(t) ? 0 : t, 2); Serial.print(",");
      Serial.print(isnan(h) ? 0 : h, 2); Serial.print(",");
    } else {
      Serial.print("NaN,NaN,");
    }

    if (bme_ok) {
      Serial.print(bme.readPressure() / 100.0F, 1); Serial.print(",");
    } else {
      Serial.print("NaN,");
    }

    // CO2 ya fue leído arriba, no re-leer (tarda 6.5s)
    Serial.print("(ver arriba),");

    if (adxl_ok) {
      Serial.print(leerAcelerometroInstantaneo(), 2);
    } else {
      Serial.print("NaN");
    }

    Serial.println();
    Serial.println();
  }

  delay(50); // Estabilidad del loop
}

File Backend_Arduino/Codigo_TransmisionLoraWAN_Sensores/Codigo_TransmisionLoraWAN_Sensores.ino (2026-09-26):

#include "LoRaWan_APP.h"
#include "Arduino.h"
#include <Wire.h>
#include <Adafruit_Sensor.h>
#include <Adafruit_BME280.h>
#include <Adafruit_SHT31.h>
#include <SparkFun_SCD4x_Arduino_Library.h>
#include <Adafruit_ADXL345_U.h>

// ================== LoRaWAN Credenciales ==================
// devEui/appEui/appKey viven en secrets.h (IGNORADO por git).
// Copiar secrets.h.example -> secrets.h y completar con los valores de TTN.
#include "secrets.h"

uint32_t devAddr = 0;
uint8_t nwkSKey[] = { 0 };
uint8_t appSKey[] = { 0 };

LoRaMacRegion_t loraWanRegion = LORAMAC_REGION_AU915;
DeviceClass_t   loraWanClass  = CLASS_A;
bool overTheAirActivation = true;
bool loraWanAdr           = true; // Lo devolvemos a la normalidad
bool isTxConfirmed        = false;
uint8_t appPort           = 2;
uint8_t confirmedNbTrials = 8;
bool keepNet              = true;

// ======== EL CAMBIO ESTÁ AQUÍ ========
// Cambiamos el penúltimo valor de 0x0002 a 0x0000. 
// Esto apaga los canales de 500kHz y fuerza a la placa a unirse en DR2 o DR3.
uint16_t userChannelsMask[6] = { 0xFF00, 0x0000, 0x0000, 0x0000, 0x0000, 0x0000 };
uint32_t appTxDutyCycle = 20000;

// ================== Sensores ==================
Adafruit_BME280 bme;
Adafruit_SHT31  sht30 = Adafruit_SHT31();
SCD4x           scd41;
Adafruit_ADXL345_Unified accel = Adafruit_ADXL345_Unified(12345);

#define PIN_INTERRUPCION GPIO5

volatile bool flag_interrupcion  = false;
bool     impactoPendiente        = false;
uint16_t aceleracionGuardada     = 0;

// ================== CONFIGURAR ADXL345 ==================
void configurarADXL345()
{
  if (!accel.begin())
  {
    Serial.println("WARNING: ADXL345 no detectado. Continuando sin acelerómetro.");
    return;
  }

  accel.setRange(ADXL345_RANGE_16_G);

  Wire.beginTransmission(0x53);
  Wire.write(0x24); Wire.write(10);  // THRESH_ACT
  Wire.endTransmission();

  Wire.beginTransmission(0x53);
  Wire.write(0x27); Wire.write(0x70); // ACT_INACT_CTL
  Wire.endTransmission();

  Wire.beginTransmission(0x53);
  Wire.write(0x2E); Wire.write(0x10); // INT_ENABLE → Activity (bit 4, no DATA_READY)
  Wire.endTransmission();

  Wire.beginTransmission(0x53);
  Wire.write(0x2F); Wire.write(0x00); // INT_MAP → INT1
  Wire.endTransmission();

  delay(50);
}

// ================== LEER ACELERACIÓN ==================
float leerAcelerometroInstantaneo()
{
  sensors_event_t event;
  accel.getEvent(&event);

  float ax = event.acceleration.x;
  float ay = event.acceleration.y;
  float az = event.acceleration.z;
  float magnitud = sqrt(ax * ax + ay * ay + az * az);

  // Limpiar flag de interrupción
  Wire.beginTransmission(0x53);
  Wire.write(0x30);
  Wire.endTransmission(false);
  Wire.requestFrom((uint8_t)0x53, (uint8_t)1);
  Wire.read();

  return abs(magnitud - 9.81);
}

// ================== INTERRUPCIÓN ==================
void ISR_Movimiento()
{
  flag_interrupcion = true;
}

// ================== PAYLOAD ==================
void prepareTxFrame(uint8_t port)
{
  Wire.setClock(50000);

  float temp = sht30.readTemperature();
  float hum  = sht30.readHumidity();
  float pres = bme.readPressure() / 100.0F;

  uint16_t co2 = 0;
  scd41.measureSingleShot();
  
  bool medicionLista = false;
  for (int i = 0; i < 13; i++) {
    delay(500);
      // En esta librería, false significa lectura exitosa sin error
    if (scd41.readMeasurement() == false) {
      co2 = scd41.getCO2();
      medicionLista = true;
      break;
    }
  }
  
  if (!medicionLista) {
    Serial.println("WARNING: SCD41 sin datos en 6.5s");
  }

  if (!impactoPendiente) {
    float inst = leerAcelerometroInstantaneo();
    aceleracionGuardada = (uint16_t)(inst * 10);
  }

  int16_t t = isnan(temp) ? 0 : (int16_t)(temp * 100);
  int16_t h = isnan(hum)  ? 0 : (int16_t)(hum  * 100);
  int16_t p = isnan(pres) ? 0 : (int16_t)(pres * 10);  // conserva 1 decimal

  appDataSize = 11;
  appData[0]  = highByte(t);
  appData[1]  = lowByte(t);
  appData[2]  = highByte(h);
  appData[3]  = lowByte(h);
  appData[4]  = highByte(p);
  appData[5]  = lowByte(p);
  appData[6]  = highByte(co2);
  appData[7]  = lowByte(co2);
  appData[8]  = impactoPendiente ? 1 : 0;
  appData[9]  = highByte(aceleracionGuardada);
  appData[10] = lowByte(aceleracionGuardada);

  impactoPendiente    = false;
  aceleracionGuardada = 0;
}

// ================== SETUP ==================
void setup()
{
  Serial.begin(115200);

  pinMode(Vext, OUTPUT);
  digitalWrite(Vext, LOW); 
  delay(3000); 

  Wire.begin();
  Wire.setClock(50000);

  // BME280
  if (!bme.begin(0x76) && !bme.begin(0x77)) {
    Serial.println("WARNING: BME280 no detectado.");
  }
  
  // SHT30
  if (!sht30.begin(0x44)) {
    Serial.println("WARNING: SHT30 no detectado en 0x44.");
  }

  // SCD41
  if (!scd41.begin(Wire)) {
    Serial.println("WARNING: SCD41 no detectado en setup.");
  }
  delay(600);

  configurarADXL345();

  pinMode(PIN_INTERRUPCION, INPUT_PULLDOWN);
  attachInterrupt(digitalPinToInterrupt(PIN_INTERRUPCION), ISR_Movimiento, RISING);

  deviceState = DEVICE_STATE_INIT;
}

// ================== LOOP ==================
void loop()
{
  if (flag_interrupcion)
  {
    flag_interrupcion = false;
    float valorImpacto  = leerAcelerometroInstantaneo();
    aceleracionGuardada = (uint16_t)(valorImpacto * 10);
    impactoPendiente    = true;
  }

  if (impactoPendiente && deviceState == DEVICE_STATE_SLEEP)
  {
    if (IsLoRaMacNetworkJoined) deviceState = DEVICE_STATE_SEND;
    else                        impactoPendiente = false;
  }

  switch (deviceState)
  {
    case DEVICE_STATE_INIT:
      delay(200);
      LoRaWAN.init(loraWanClass, loraWanRegion);
      deviceState = DEVICE_STATE_JOIN;
      break;
    case DEVICE_STATE_JOIN:
      LoRaWAN.join();
      break;
    case DEVICE_STATE_SEND:
      prepareTxFrame(appPort);
      LoRaWAN.send();
      deviceState = DEVICE_STATE_CYCLE;
      break;
    case DEVICE_STATE_CYCLE:
      txDutyCycleTime = appTxDutyCycle + randr(0, 2000);
      LoRaWAN.cycle(txDutyCycleTime);
      deviceState = DEVICE_STATE_SLEEP;
      break;
    case DEVICE_STATE_SLEEP:
      LoRaWAN.sleep();
      break;
    default:
      deviceState = DEVICE_STATE_INIT;
      break;
  }
}

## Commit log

2026-04-27 Cambio TOTAL al github, subimos de nuevo los archivos
    [sensor_data.csv]
2026-04-27 remove unwanted files
    [sensor_data.csv]
2026-06-07 Agregado de archivos importantes
    [ESTACA BOCETO (PUNTA DE LANZA) f.f3d, Modelo3D_PCB_ArribaLanza.kicad_pcb, Modelo3D_PCB_ArribaLanza.kicad_sch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]
2026-06-22 Refactorización y Mejora de la Página Web
    [ESTACA BOCETO (PUNTA DE LANZA) f.f3d, Modelo3D_PCB_ArribaLanza.kicad_pcb, Modelo3D_PCB_ArribaLanza.kicad_sch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]
2026-09-25 Actualizacion AGRILION + limpieza y fixes
    - Actualizacion completa del proyecto (frontend, AppCelular, backend,
    IA, docs, docker).
    - Removido proyecto Next.js anidado paginaweb/mi-app (boilerplate
    duplicado); restaurado paginaweb/package-lock.json.
    - Secretos fuera del repo: tokens InfluxDB, sensores.db y claves de
    ejemplo en .env.example quedaron como placeholders (los archivos
    reales siguen en disco local, ignorados por git).
    - .gitignore: fix PaginaWeb->paginaweb, agregado *.db, tokens,
    __pycache__.
    - paginaweb: eslint y tsc en cero (hooks puros, tipos estrictos en
    shaders WebGL/Three.js, imports sin usar).
    - CLAUDE.md actualizado a la estructura real.
2026-09-26 Integracion E2E completa + fixes de dashboard y limpieza
    Backend IoT: device_registry (device->silo con fallback), topic TTN con app_id real, puerto 8883, processor sin duplicar bridge, score 0-100, estado al cambiar riesgo, main.py lanzador, UTF-8 en Windows, secretos LoRaWAN a secrets.h.
    AI API: load_dotenv y CORS por env, fix crash del chat y contexto real de sensores, overview expone grano/device desde Influx, register_sensor guarda grainType.
    Web: Firebase Auth real (login/registro/Google/reset), alta de silo+sensor, sin fallback silencioso a mock ni datos inventados, umbrales unificados 30/70, badges/contadores reales, logout, estado vacio, paginas legales, sitemap/OG, build SSR arre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
    [Codigo_TransmisionLoraWAN_Sensores.ino]
2026-10-11 Fix CO2 del firmware (SCD41) + scripts de TTN
    Firmware: readMeasurement invertido (ahora lee el dato fresco), single-shot sin medicion periodica, sensor SCD41 explicito y compensacion de presion con BME280. Scripts: listen_ttn.py (uplinks en vivo) y rotate_appkey.py (rotacion de AppKey via API).
2026-10-13 Firmware: radio estable + lecturas reales + watchdog de join auto-recuperable
    - Vext controlado solo por el firmware (LORAWAN_RGB=0): sensores encendidos
    unicamente durante la lectura, apagados antes del TX (evita Tx Timeout).
    - Descarga del bus I2C con los sensores apagados: evita alimentacion fantasma
    y permite lecturas reales en cada frame (t/h/p validados en serie).
    - Watchdog: reinicio automatico si el join no se completa en 150s (el primer
    intento de cada arranque va en FSB2; se auto-recupera cuando vuelve el gateway).
    - Flag AGRILION_CO2 y estado del SCD41 documentado (single-shot NACK -> co2=0).
    - Fix topic TTN v3/{app}@ttn/devices/+/up en TTN_MQTT.py y scripts.
    - scripts/flash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
2026-10-25 Integracion E2E: presion, CO2, chatbot LLM local y fixes de UI
2026-10-25 App Android: rediseno de pantallas, tokens y assets
2026-10-25 UI: gauge de riesgo limpio sin bandas superpuestas
2026-10-25 Firmware: ADXL345 antes del SCD41 y descarte de impactos invalidos
2026-10-25 Android: configurar API, perfil y mejoras de UX
2026-10-26 feat: integrar GPS Air530Z y mapas de silos
    Firmware v2 de 23 bytes con GPS siempre encendido, decodificadores TTN/local, persistencia GPS en InfluxDB/Firestore, API con coordenadas, mapa osmdroid en Android y mapa Leaflet con gate de autentic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
2026-10-26 feat: estados offline, modo demo y mejoras de entrega
    Detecta datos vencidos en web y Android, muestra avisos de sin datos, agrega modo demo con coordenadas y mapa sin login, mejora el dashboard con refresh y estado de API, suma seccion Como funciona y CTAs al hero, elimina sparklines simuladas, corrige textos ilustrativos, accesibilidad y documentacion de demo.
2026-10-27 feat: seguridad de API, sesiones web y tokens Android
    Autentica endpoints de usuario con Firebase ID token, filtra silos por propietario, protege el dashboard real con sesion httpOnly, protege /ingest con clave interna, agrega tokens a Android, refuerza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
2026-10-27 security: verificar revocación de tokens Firebase
2026-10-28 build: APK de demo con API local configurable
2026-10-28 docs: APK de demo con túnel remoto
2026-10-28 feat: auto-scroll lento en la landing
2026-10-28 tweak: acelerar auto-scroll de la landing
2026-10-28 feat: mapa movil sin GPS, migracion de URL y landing mas rapida
2026-10-28 fix: landing sin boundary de carga bloqueante y scroll mas rapido
2026-10-28 fix: quitar loading global que bloqueaba la landing
2026-10-28 tweak: landing a 48 px/s
